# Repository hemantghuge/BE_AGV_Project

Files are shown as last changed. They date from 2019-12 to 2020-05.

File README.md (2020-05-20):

# BE_AGV_Project 2019-2020

## Project Title
Smart and Efficient Techniques for Automated Guided Vehicle

## College
Government College of Engineering and Research, Avasari (Khurd)

## Department
Electronics and Telecommunication Engineering

#### Click below for viewing YouTube video.

YouTube video (https://www.youtube.com/watch?v=_118klFem0o)

## Mentor

**Name:** Dr. Kirti Vasant Thakur
**Email ID:** kirti79@gmail.com

## Members

**Roll No.**: 16131002 **Name:** Aadesh Rambhau Borate **Email ID:** aadeshborate5@gmail.com

**Roll No.:** 16131035 **Name:** Hemant Goraksh Ghuge **Email ID:** hemantgghuge@gmail.com

**Roll No.:** 16131052 **Name:** Unnati Raju Kulkarni **Email ID:** unnatikulkarni46@gmail.com

**Roll No.:** 17231025 **Name:** Revati Anand Kulkarni **Email ID:** kulkarnirevati988@gmail.com

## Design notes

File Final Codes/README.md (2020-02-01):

# NOTE

**Store the final codes as given below:-**

ArduinoMega.ino

RaspberryPi.py

ArduinoNano.ino

NodeMCU.ino

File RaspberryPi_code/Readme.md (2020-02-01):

## NOTE
It is a repository where all the tested code for Raspberry Pi is stored.

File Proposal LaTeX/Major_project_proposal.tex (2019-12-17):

\documentclass[12pt]{article}
\usepackage[utf8]{inputenc}
\usepackage{cite}
\usepackage{graphicx}

\title{Smart and Efficient Techniques for Automated Guided Vehicle}
\author{Team ID 11, eYIC 19-20}
\date{December 2019}

\begin{document}

\maketitle

\section*{Keywords}
eYIC 19-20, SDG, AGV, Machine Vision, PCB, Versatile, Path Planning, Self  Charging, Remote Accessing

\section{Introduction}

Today the automated guided vehicle (AGV) plays an important role in the design and growth of new factories and warehouses. It is a robot that follows markers or wires in the floor or uses vision or lasers.  In an automated process, AGVs are programmed to communicate with other robots to ensure the product is moved smoothly through the warehouse, whether it is being stored for future use or sent directly to shipping areas. Navigation of AGVs is performed through laser, magnetic tapes, machine vision. As per increasing technologies, industries lack adaptive AGVs. That means, AGVs with constant hardware and software upgrades. Lack of vision-based navigation in the AGVs, make them single task-oriented. So, here we are proposing the advanced version of machine vision-based smart automated guided vehicle which incorporates the ML algorithm and would be beneficial for predicting the failures/problem before time and increasing task efficiency and accuracy. The proposed AGV also contains self-charging and can predict the possible future working hours of it. This adaptive AGV is low-cost since it must eventually attract more industries from various fields. Deploying it for repetitive material handling tasks can also allow enterprises to save on labor costs and reassign staff on other essential tasks, such as enhancing customer satisfaction.

\section{Literature Survey}

The automated guided vehicle represents the progress of automation in the industrial field. The first AGV was brought to market in the1950s, by Barrett Electronics \cite{agv_wiki}. Later in 2001, Fujimoto, Tomoya, Jun Ota, Tamio Arai, Tsuyoshi Ueyama, and Tsuyoshi Nishiyama proposed a way of estimation positioning error with magnetic tape to attempt fixed model learning to prevent stationary error while AGV runs iteratively\cite{fujimoto2001}. After in 2006, the authors Vis, Iris FA specify more specific research perspectives in the design and control of AGV systems in distribution and transportation systems. It concluded that new analytical and simulation models need to develop for large AGV systems to overcome large computational time, NP-completeness, congestion, deadlock, and delays in the system and finite planning horizons\cite{iris2006}. According to the research, the global Automated Guided Vehicle (AGV) market size was valued at USD 2.49 billion in 2018 and is projected to expand at a CAGR of 15.8\% from 2019 to 2025”\cite{grandviewresearch_site}. 

\section{Hardware Requirements}

\begin{enumerate}
    \item ATmega2560 Board
    \item Arm Cortex A53 Board
    \item ESP8266 Board
    \item ATmega328p Board
    \item Logitech C270 Webcam
    \item Monster Moto Shield VNH2SP30 Motor Driver 14A (Peak 30A)
    \item Johnson Geared Motor-Grade A Quality-300RPM
    \item MPU-6050 3-Axis Accelerometer and Gyro Sensor
    \item XL4015 5A Step Down Adjustable Power Supply with LED Voltmeter
    \item 58mm Plastic Omni Wheel for Lego
\end{enumerate}

\section{Software Requirements}

\begin{itemize}
  \item Autodesk Fusion
  \item Autodesk Eagle
  \item MATLAB \& Simulink
  \item Arduino IDE
  \item Python IDE
\end{itemize}

\section{Implementation}

Automated guided vehicles are mainly used for the transfer of loads from one place to another in industries. The implementation of proposed AGV is represented using Six modules.

\begin{figure}[htp]
\centering
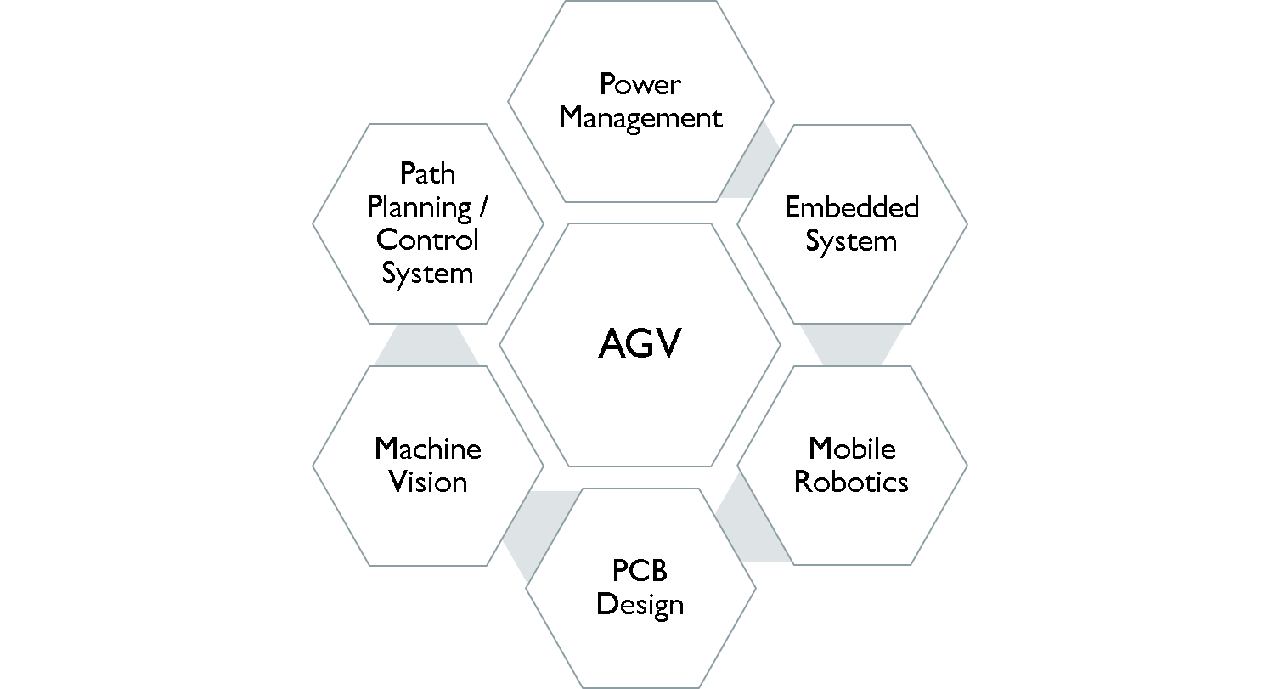
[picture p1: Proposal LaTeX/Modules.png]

\caption{Modules}
\label{fig}
\end{figure}

\begin{itemize}
  \item Power management: To make AGV more efficient the power management unit is integrated, which allows AGV to charge batteries without human interference. MCP 73831 IC is used for charging circuits and power management systems. It also regulates the voltage and current being provided for the whole circuitry of the AGV. Battery level can be indicated using LEDs for manual operation as well. This helps to increase productivity and save time.
  \item Embedded system: It includes ATmega 2660 controller board, Cortex A53 board, communication modules along with supportive software like Arduino IDE, Python IDE, Matlab, etc. Here, ATmega 2560 acts as a master controller. Data administration is done using the ESP8266 module and stored on the cloud.
  \item Pcb design: Self-designed PCB for AGV helps it to work in a multi-domain environment without major hardware changes. It performs power optimization and reduces circuitry. Each module has its own PCB board.
  \item Machine vision:  Machine vision operation is carried out using a web camera and cortex A53 controller board. A self-developed line following algorithm is used for navigation. It also performs obstacle avoidance and prevents occlusion.
  \item Path planning and control system: inertial measurement unit along with PID helps to keep AGV alined. IMU communicates with ATmega 2560 using the i2c bus. DC motor with 300rpm and 6kg-cm is controlled by a VNH2SP30 motor driver.

\end{itemize}
\newpage
\section{Flow Chart}

The working flow of the proposed automated guided vehicle is explained in the below flowchart.

\begin{figure}[htp]
\centering
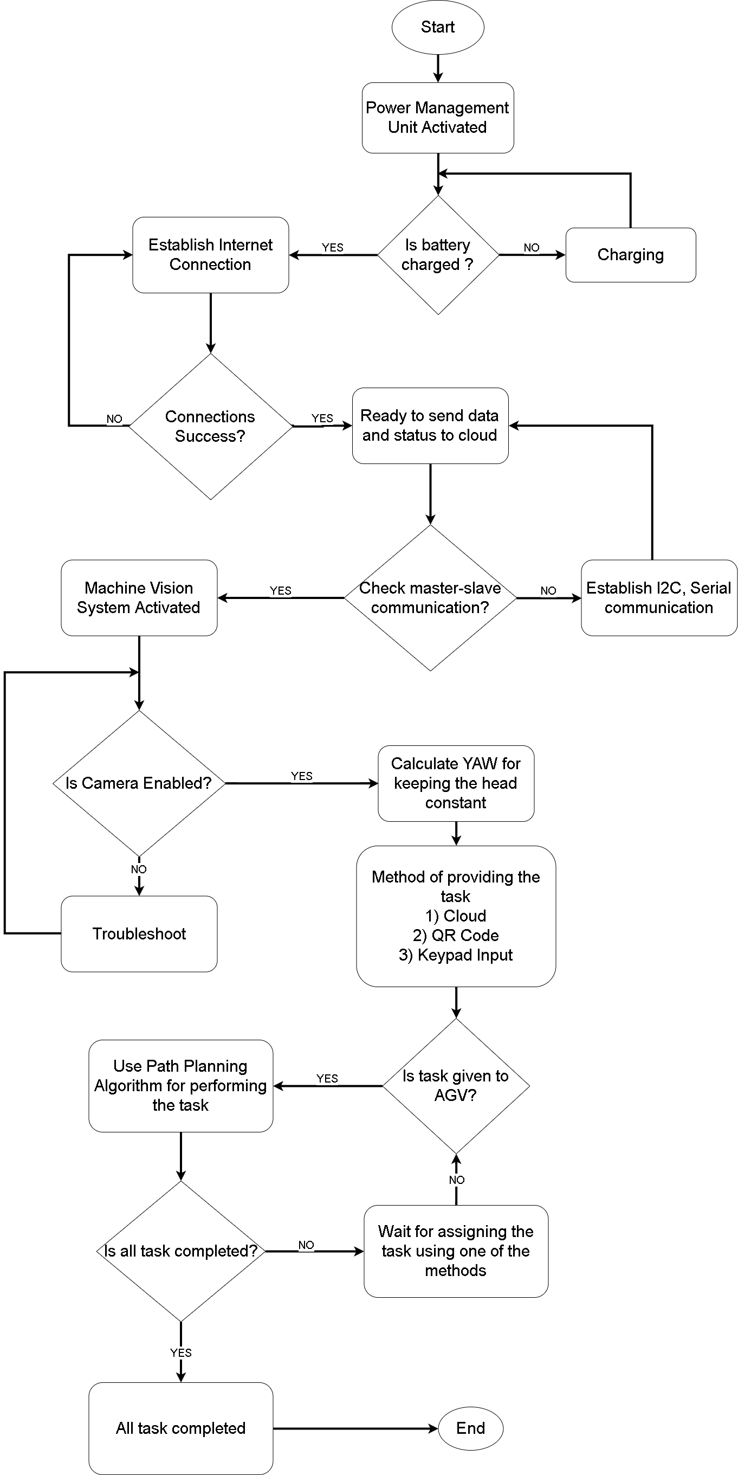
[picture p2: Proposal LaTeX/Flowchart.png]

\caption{Flow Chart}
\label{fig}
\end{figure}
\newpage
\begin{enumerate}
    \item When AGV is assigned a particular task, firstly it checks whether the battery is charged or not. If it is not AGV will move to the charging station and wait till charging.
    \item Once the battery is checked, AGV establishes an internet connection in order to manage data, and check whether the connection is successful or not.
    \item When all these primary tasks are completed, AGV is ready to perform the assigned task.
    \item In order to perform a task, it needs to check the controller’s communication with slaves. If it is ok the working continues. And if not it establishes necessary communication.
    \item For the movement of proposed AGV, it needs machine vision so, firstly it enables the webcam and necessary hardware successfully. A self-developed path planning algorithm is used for navigation.
    \item The task can be given to AGV through remote accessing using the cloud, QR code or keypad input.
    \item After that, AGV checks whether the assigned task is completed or not if not completed, it waits till the completion of the task and checks for the next task.
\end{enumerate}

\section{Feasibility}

The entire concept of AGVs is based on the system of Flexible Manufacturing Systems (FMS). Machine vision and implementation of ML in AGV provide flexibility by activating operational activities in case of any unpredicted problems and issues including data visualization and analyzation. By automating the battery charging operation, several developments to the AGV technology can be enabled for reducing the charging time of the batteries, leading to a further increase in the efficiency and output of the automation. Our self-developed algorithm and PID- controller assures accuracy and stabilization in navigation respectively.

%\cite{agv_wiki}
%\cite{fujimoto2001}
%\cite{iris2006}
%\cite{grandviewresearch_site}
%\cite{isozaki2011}
%\cite{lozoya2007}
%\cite{piyare2011}
%\cite{cardarelli2015}

\bibliographystyle{plain}
\bibliography{ref}

\end{document}

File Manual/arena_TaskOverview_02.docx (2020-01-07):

Automated Guided Vehicle

1.1 Introduction:

Today the Automated guided vehicle plays an important role in the design of new factories and warehouses. In an automated process, AGVs are programmed to communicate with other robots to ensure the product is moved smoothly through the warehouse, whether it is being stored for future use or sent directly to shipping areas. AGV is one kind of transportation that follows the given respective paths and route. It is widely used industrial fields and community services as well as in dangerous working it is able to sense and respond in the given environment.

The first AGV was brought to market in the 1950s, by Barrett Electronics of Northbrook, and at the time it was simply a tow truck that followed a wire in the floor instead of a rail. Over the years the technology has become more sophisticated and today automated vehicles are mainly Laser navigated ex: LGV which works more accurately and precisely in industrial fields, manufacturing processes medical fields. The robot perform hard, dangerous and accurate work in order to make our life easy as they can work for hours without taking rest. They can work without making errors in very less time. The AGV can also store objects on a bed. The objects can be placed on a set of the conveyor and then pushed off by reversing them. Some AGVs use forklifts to lift objects for storage. AGVs are employed in nearly every industry, including, pulp, paper, metals, newspaper, and general manufacturing. Transporting materials such as food, linen or medicine in hospitals is also done. An AGV can also be called a laser guided vehicle (LGV) or self-guided vehicle (SGV). Lower cost versions of AGVs are often called Automated Guided Carts (AGCs) and are usually guided by magnetic tape.

Types of navigation in AGV’S

● Wired navigation - A slot is cut in to the floor and a wire is placed approximately 1 inch below the surface. This slot is cut along the path the AGV is to follow. This wire is used to transmit a radio signal. A sensor is installed on the bottom of the AGV close to the ground. The sensor detects the relative position of the radio signal being transmitted from the wire. This information is used to regulate the steering circuit, making the AGV follow the wire.

● Guide tape navigation - AGVs use tape for the guide path. The AGV is fitted with the appropriate guide sensor to follow the path of the tape. One the major advantage of tape over wired guidance is that can be easily removed and relocated if the course needs to change. Coloured tape is initially less expensive, but lacks the advantage of being embedded in high traffic areas where the tape may become damaged or dirty. The flexible magnetic bar can also be embedded in the floor like wire but works under the same provision as magnetic tape and so remains unpowered or passive. Another advantage of magnetic guide tape is the dual polarity.

● Laser target navigation - The navigation is done by mounting reflective tape on walls, poles or fixed machines. The AGV carries a laser transmitter and receiver on a rotating turret. The laser is transmitted and received by the same sensor. The angle and (sometimes) distance to any reflectors that in line of sight and in range are automatically calculated. This information is compared to the map of the reflector layout stored in the AGV’s memory. This allows the navigation system to triangulate the current position of the AGV. The current position is compared to the path programmed in to the reflector layout map. The steering is adjusted accordingly to keep the AGV on track. It can then navigate to a desired target using the constantly updating position

1.2 Arena:

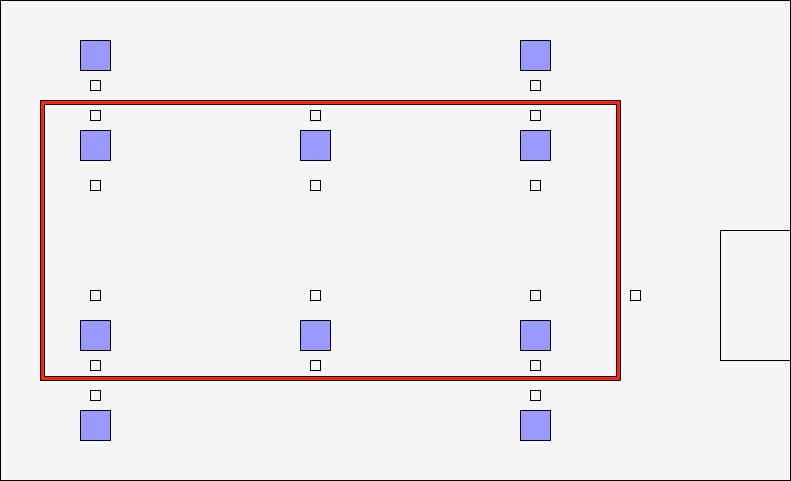
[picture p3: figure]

Battery charging

D

C

B

A

Fig 1

For the demonstration of our project, here is the prototype of a warehouse. Blue boxes indicate the locations to and from which material is transported from one position to another. Red line marked is the line on which the AGV can travel using sensors or machine vision. The smaller boxes on either side of the line as well as in the front of blue boxes represent QR codes with which path planning and actions to be performed can be decided.

1.3 Tasks:

There are 3 sections in which the demonstration is divided. Let us call them D1, D2, D3 for the sake of convenience.

1. D1:

Here AGV will use machine vision for the line following application. This will be demonstrated on the red line shown in the figure1. QR codes on the either side of the line are used for decision of pick or place. A, B, C, D are the positions for pick and place application. Side arms present on either side of the AGV are used for it. Configured QR codes pasted on the floor will work as feedback in decision making.

2. D2:

This section will be demonstrated in the internal part of red line. Here we are mainly focusing on the path planning algorithm. Node numbers or values are predefined for the positions in the QR code. By using By using an user interface and IoT platform, start point and destination points are provided to AGV. The optimum path will be decided by the AGV itself. A load cell is used as a feedback to prevent overloading condition.

3. D3:

This is the more advanced feature of AGV. Here AGV will follow a particular person. Machine learning algorithm will be implemented for the same. Also the load cell is used for the preventing overloading.

4. D4:

This is the self-charging feature in which the low battery level will be detected and it will move automatically towards battery charging station. The position of the battery charging station will be decided by a special QR code.

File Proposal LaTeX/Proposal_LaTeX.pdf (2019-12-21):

# Smart and Efficient Techniques for Automated Guided Vehicle

### Team ID 11, eYIC 19-20

### December 2019

## Keywords

eYIC 19-20, SDG, AGV, Machine Vision, PCB, Versatile, Path Planning, Self Charging, Remote Accessing

## 1 Introduction

Today the automated guided vehicle (AGV) plays an important role in the design and growth of new factories and warehouses. It is a robot that follows markers or wires in the floor or uses vision or lasers. In an automated process, AGVs are programmed to communicate with other robots to ensure the product is moved smoothly through the warehouse, whether it is being stored for future use or sent directly to shipping areas. Navigation of AGVs is performed through laser, magnetic tapes, machine vision. As per increasing technologies, industries lack adaptive AGVs. That means, AGVs with constant hardware and software upgrades. Lack of vision-based navigation in the AGVs, make them single task-oriented. So, here we are proposing the advanced version of machine vision-based smart automated guided vehicle which incorporates the ML algorithm and would be beneficial for predicting the failures/problem before time and increasing task efficiency and accuracy. The proposed AGV also contains self-charging and can predict the possible future working hours of it. This adaptive AGV is low-cost since it must eventually attract more industries from various fields. Deploying it for repetitive material handling tasks can also allow enterprises to save on labor costs and

1

reassign staff on other essential tasks, such as enhancing customer satisfaction.

## 2 Literature Survey

The automated guided vehicle represents the progress of automation in the industrial field. The first AGV was brought to market in the1950s, by Barrett Electronics [4]. Later in 2001, Fujimoto, Tomoya, Jun Ota, Tamio Arai, Tsuyoshi Ueyama, and Tsuyoshi Nishiyama proposed a way of estimation positioning error with magnetic tape to attempt fixed model learning to prevent stationary error while AGV runs iteratively [1]. After in 2006, the authors Vis, Iris FA specify more specific research perspectives in the design and control of AGV systems in distribution and transportation systems. It concluded that new analytical and simulation models need to develop for large AGV systems to overcome large computational time, NP-completeness, congestion, deadlock, and delays in the system and finite planning horizons [2]. According to the research, the global Automated Guided Vehicle (AGV) market size was valued at USD 2.49 billion in 2018 and is projected to expand at a CAGR of 15.8% from 2019 to 2025” [3].

## 3 Hardware Requirements

1. ATmega2560 Board
2. Arm Cortex A53 Board
3. ESP8266 Board
4. ATmega328p Board
5. Logitech C270 Webcam
6. Monster Moto Shield VNH2SP30 Motor Driver 14A (Peak 30A)
7. Johnson Geared Motor-Grade A Quality-300RPM
8. MPU-6050 3-Axis Accelerometer and Gyro Sensor
9. XL4015 5A Step Down Adjustable Power Supply with LED Voltmeter
10. 58mm Plastic Omni Wheel for Lego

2

## 4 Software Requirements

- Autodesk Fusion
- Autodesk Eagle
- MATLAB & Simulink
- Arduino IDE
- Python IDE

## 5 Implementation

Automated guided vehicles are mainly used for the transfer of loads from one place to another in industries. The implementation of proposed AGV is represented using Six modules.

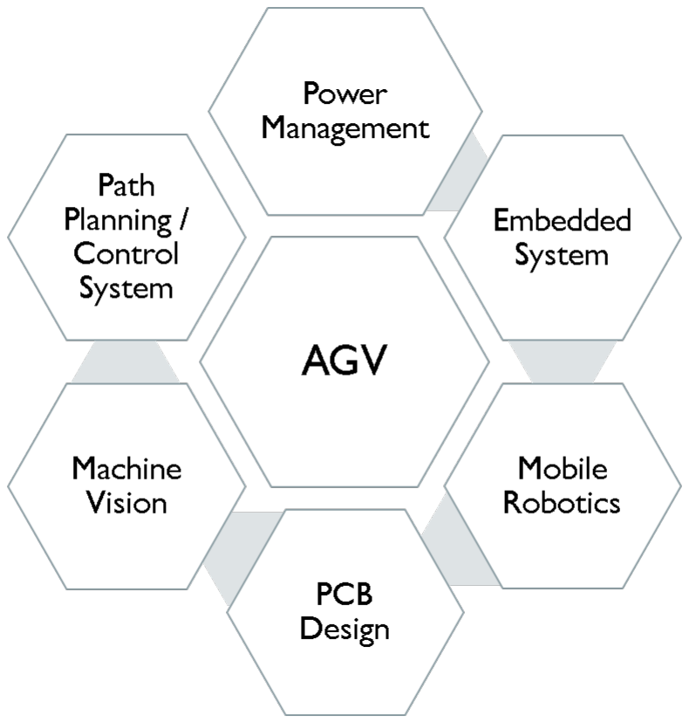
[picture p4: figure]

Figure 1: Modules

3

- Power management: To make AGV more efficient the power management unit is integrated, which allows AGV to charge batteries without human interference. MCP 73831 IC is used for charging circuits and power management systems. It also regulates the voltage and current being provided for the whole circuitry of the AGV. Battery level can be indicated using LEDs for manual operation as well. This helps to increase productivity and save time.
- Embedded system: It includes ATmega 2660 controller board, Cortex A53 board, communication modules along with supportive software like Arduino IDE, Python IDE, Matlab, etc. Here, ATmega 2560 acts as a master controller. Data administration is done using the ESP8266 module and stored on the cloud.
- Pcb design: Self-designed PCB for AGV helps it to work in a multidomain environment without major hardware changes. It performs power optimization and reduces circuitry. Each module has its own PCB board.
- Machine vision: Machine vision operation is carried out using a web camera and cortex A53 controller board. A self-developed line following algorithm is used for navigation. It also performs obstacle avoidance and prevents occlusion.
- Path planning and control system: inertial measurement unit along with PID helps to keep AGV alined. IMU communicates with ATmega 2560 using the i2c bus. DC motor with 300rpm and 6kg-cm is controlled by a VNH2SP30 motor driver.

4

## 6 Flow Chart

The working flow of the proposed automated guided vehicle is explained in the below flowchart.

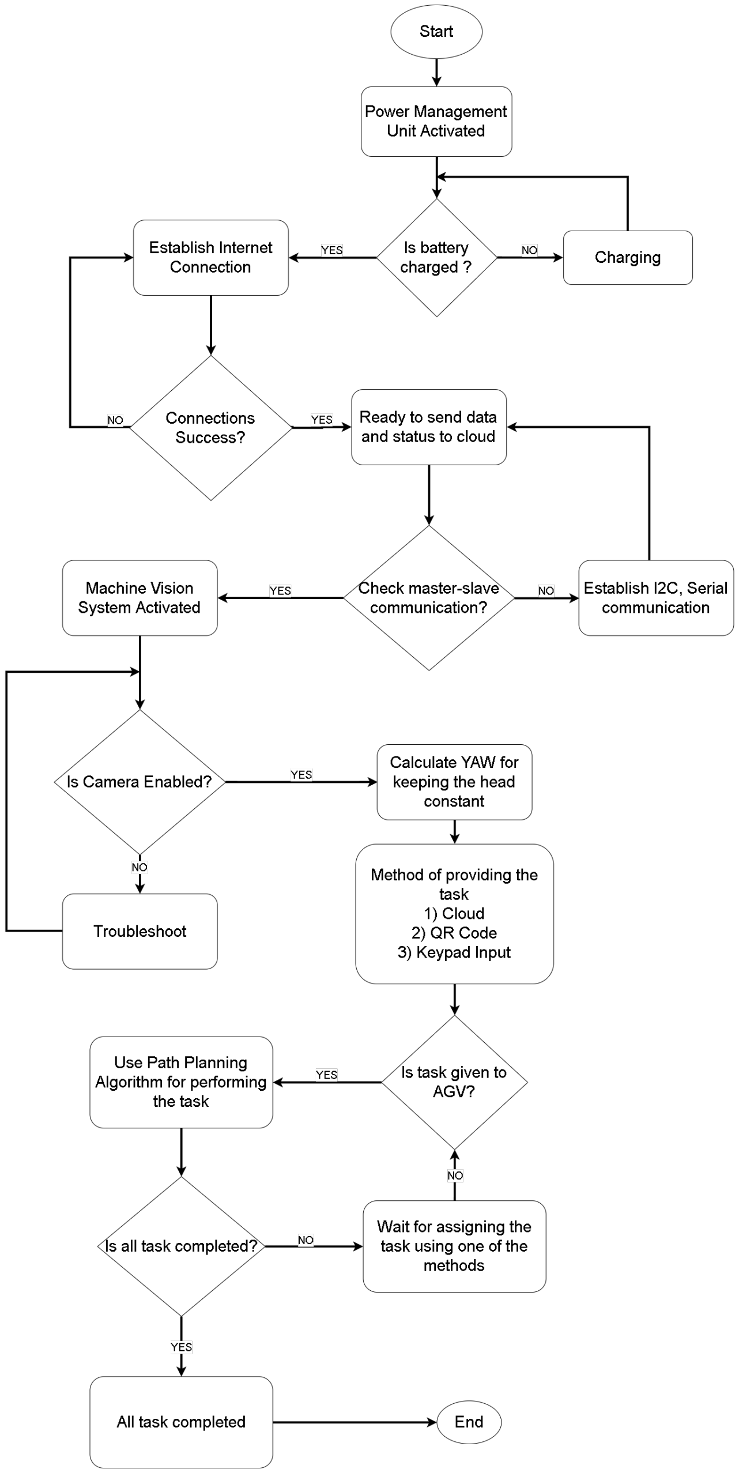
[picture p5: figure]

Figure 2: Flow Chart

5

1. When AGV is assigned a particular task, firstly it checks whether the battery is charged or not. If it is not AGV will move to the charging station and wait till charging.
2. Once the battery is checked, AGV establishes an internet connection in order to manage data, and check whether the connection is successful or not.
3. When all these primary tasks are completed, AGV is ready to perform the assigned task.
4. In order to perform a task, it needs to check the controller’s communication with slaves. If it is ok the working continues. And if not it establishes necessary communication.
5. For the movement of proposed AGV, it needs machine vision so, firstly it enables the webcam and necessary hardware successfully. A self-developed path planning algorithm is used for navigation.
6. The task can be given to AGV through remote accessing using the cloud, QR code or keypad input.
7. After that, AGV checks whether the assigned task is completed or not if not completed, it waits till the completion of the task and checks for the next task.

## 7 Feasibility

The entire concept of AGVs is based on the system of Flexible Manufacturing Systems (FMS). Machine vision and implementation of ML in AGV provide flexibility by activating operational activities in case of any unpredicted problems and issues including data visualization and analyzation. By automating the battery charging operation, several developments to the AGV technology can be enabled for reducing the charging time of the batteries, leading to a further increase in the efficiency and output of the automation. Our self-developed algorithm and PID- controller assures accuracy and stabilization in navigation respectively.

6

## References

[1] Fujimoto, Tomoya, Jun Ota, Tamio Arai, Tsuyoshi Ueyama, and Tsuyoshi Nishiyama. Semi-guided navigation of agv through iterative learning. Intelligent Robot and Systems, IEEE/RSJ International Conference, 2:968–973, 2001.
[2] A. Vis Iris, F. Survey of research in the design and control of automated guided vehicle systems. European Journal of Operational Research, 170:677–709, 2006.
[3] Grand View Research. Automated guided vehicle agv market, 2019.
[4] Wikipedia. Automated guided vehicle, 2012.

7

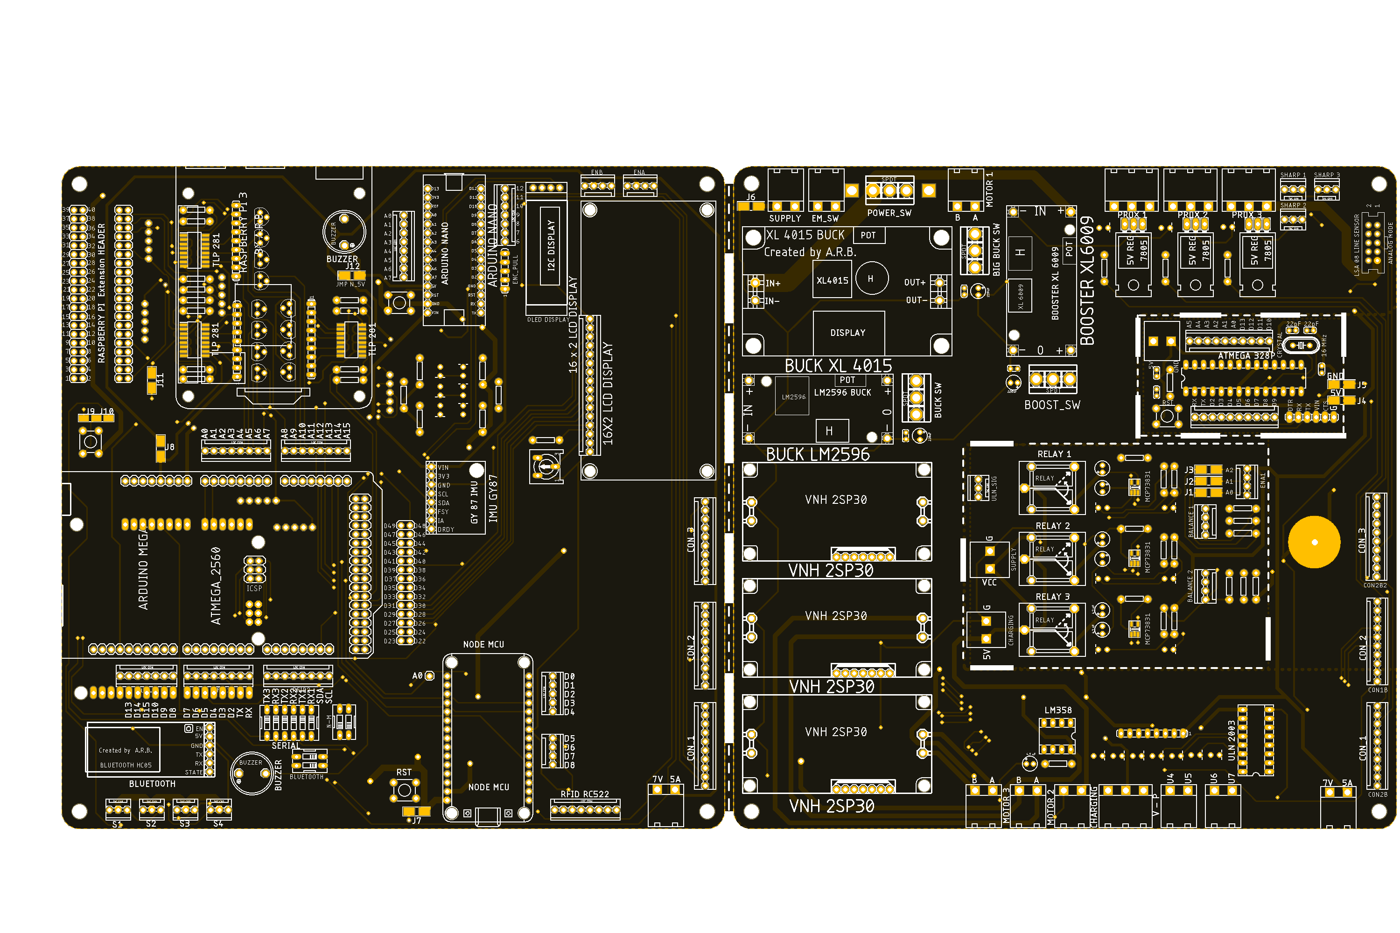
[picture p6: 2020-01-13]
PCB Files/PCB IMAGE/BLACK.png

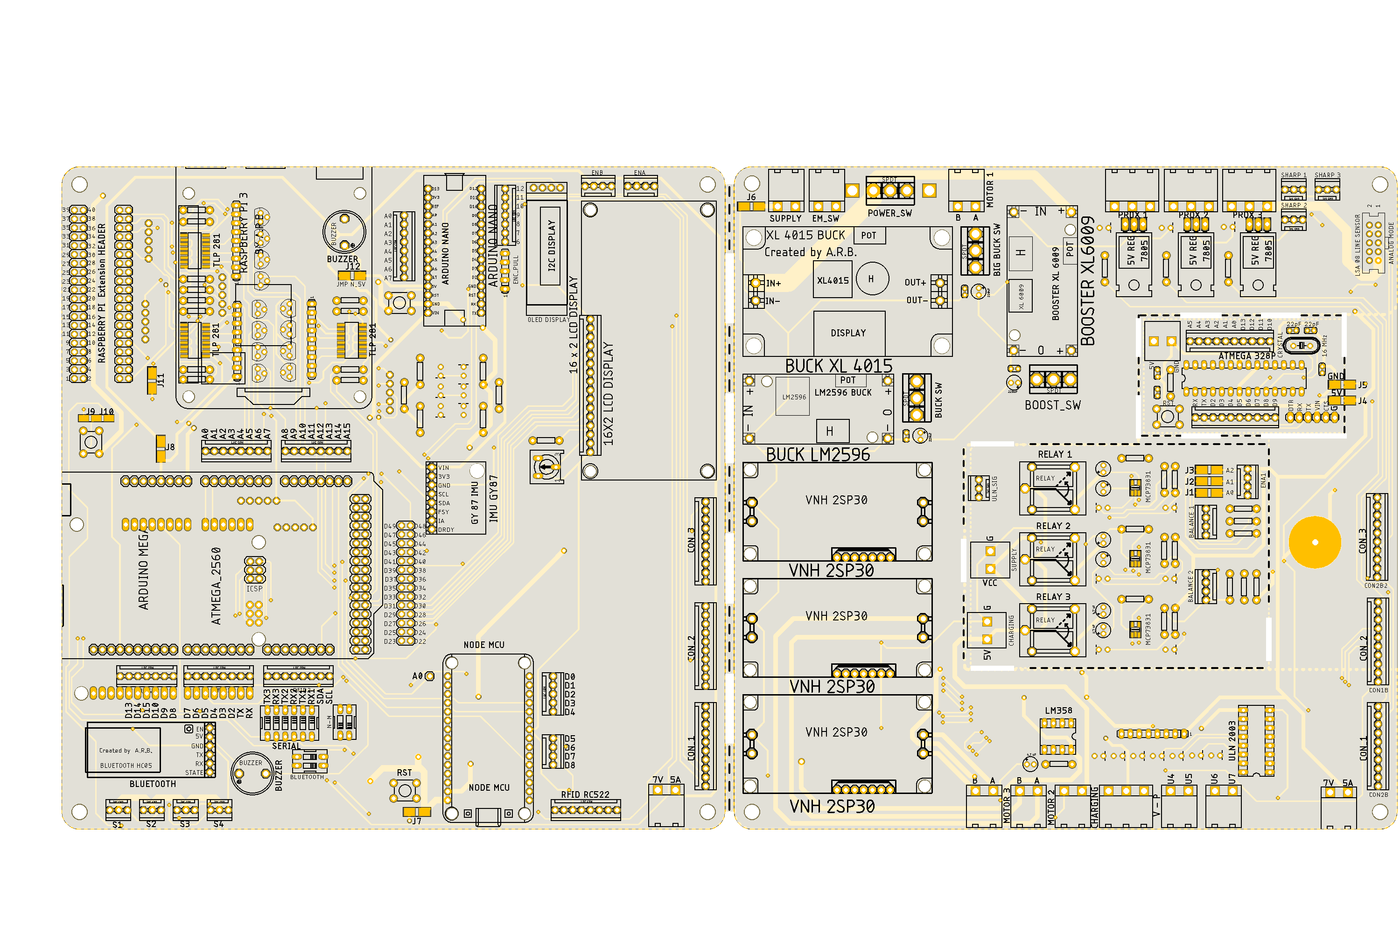
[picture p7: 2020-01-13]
PCB Files/PCB IMAGE/WHITE.png

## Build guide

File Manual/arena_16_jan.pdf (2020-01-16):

# Smart and Efficient Techniques for Automated Guided Vehicle

# 1. Arena:

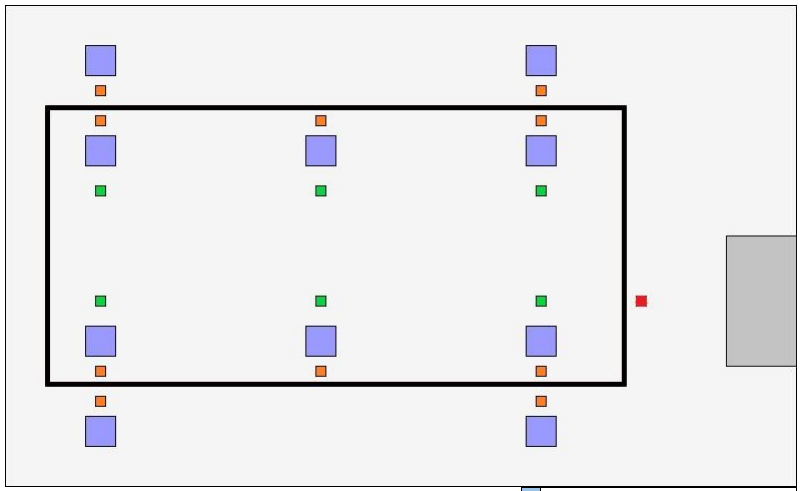
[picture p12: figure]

### Fig 1

Length * Breadth = 3300 mm * 2500 mm

There are 3 sections in which the demonstration is divided. Let us call them D1, D2, D3 for the sake of convenience.

1. D1:
Here AGV will use machine vision for the line following application. This will be demonstrated on the black line shown in the Fig 1. QR codes on the either side of the line are used for decision of pick or place. Side arms present on either side of the AGV are used for it. Configured QR codes pasted on the floor will work as feedback in decision making.

Boxes (70*70*70)
D1 QR Code(40*40)
D2 QR Code(40*40)
QR Code for battery charging Charging section

2. D2:
This section will be demonstrated in the internal part of black line. Here we are mainly focusing on the path planning algorithm. Node numbers or values are predefined for the positions in the QR code. By using user interface and IoT platform, start point and destination points are provided to AGV. The optimum path will be decided by the AGV itself. A load cell is used as a feedback to prevent overloading condition.
3. D3:
Here AGV will follow a particular person. Machine learning algorithm will be implemented for the same. Also the load cell is used for the preventing overloading.
4. D4:
This is the self-charging feature in which the low battery level will be detected and it will move automatically towards battery charging station. The position of the battery charging station will be decided by a special QR code (red box in Fig 1).

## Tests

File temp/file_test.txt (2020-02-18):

nTest file
git 
AGV
new
testing file

test 1
ready

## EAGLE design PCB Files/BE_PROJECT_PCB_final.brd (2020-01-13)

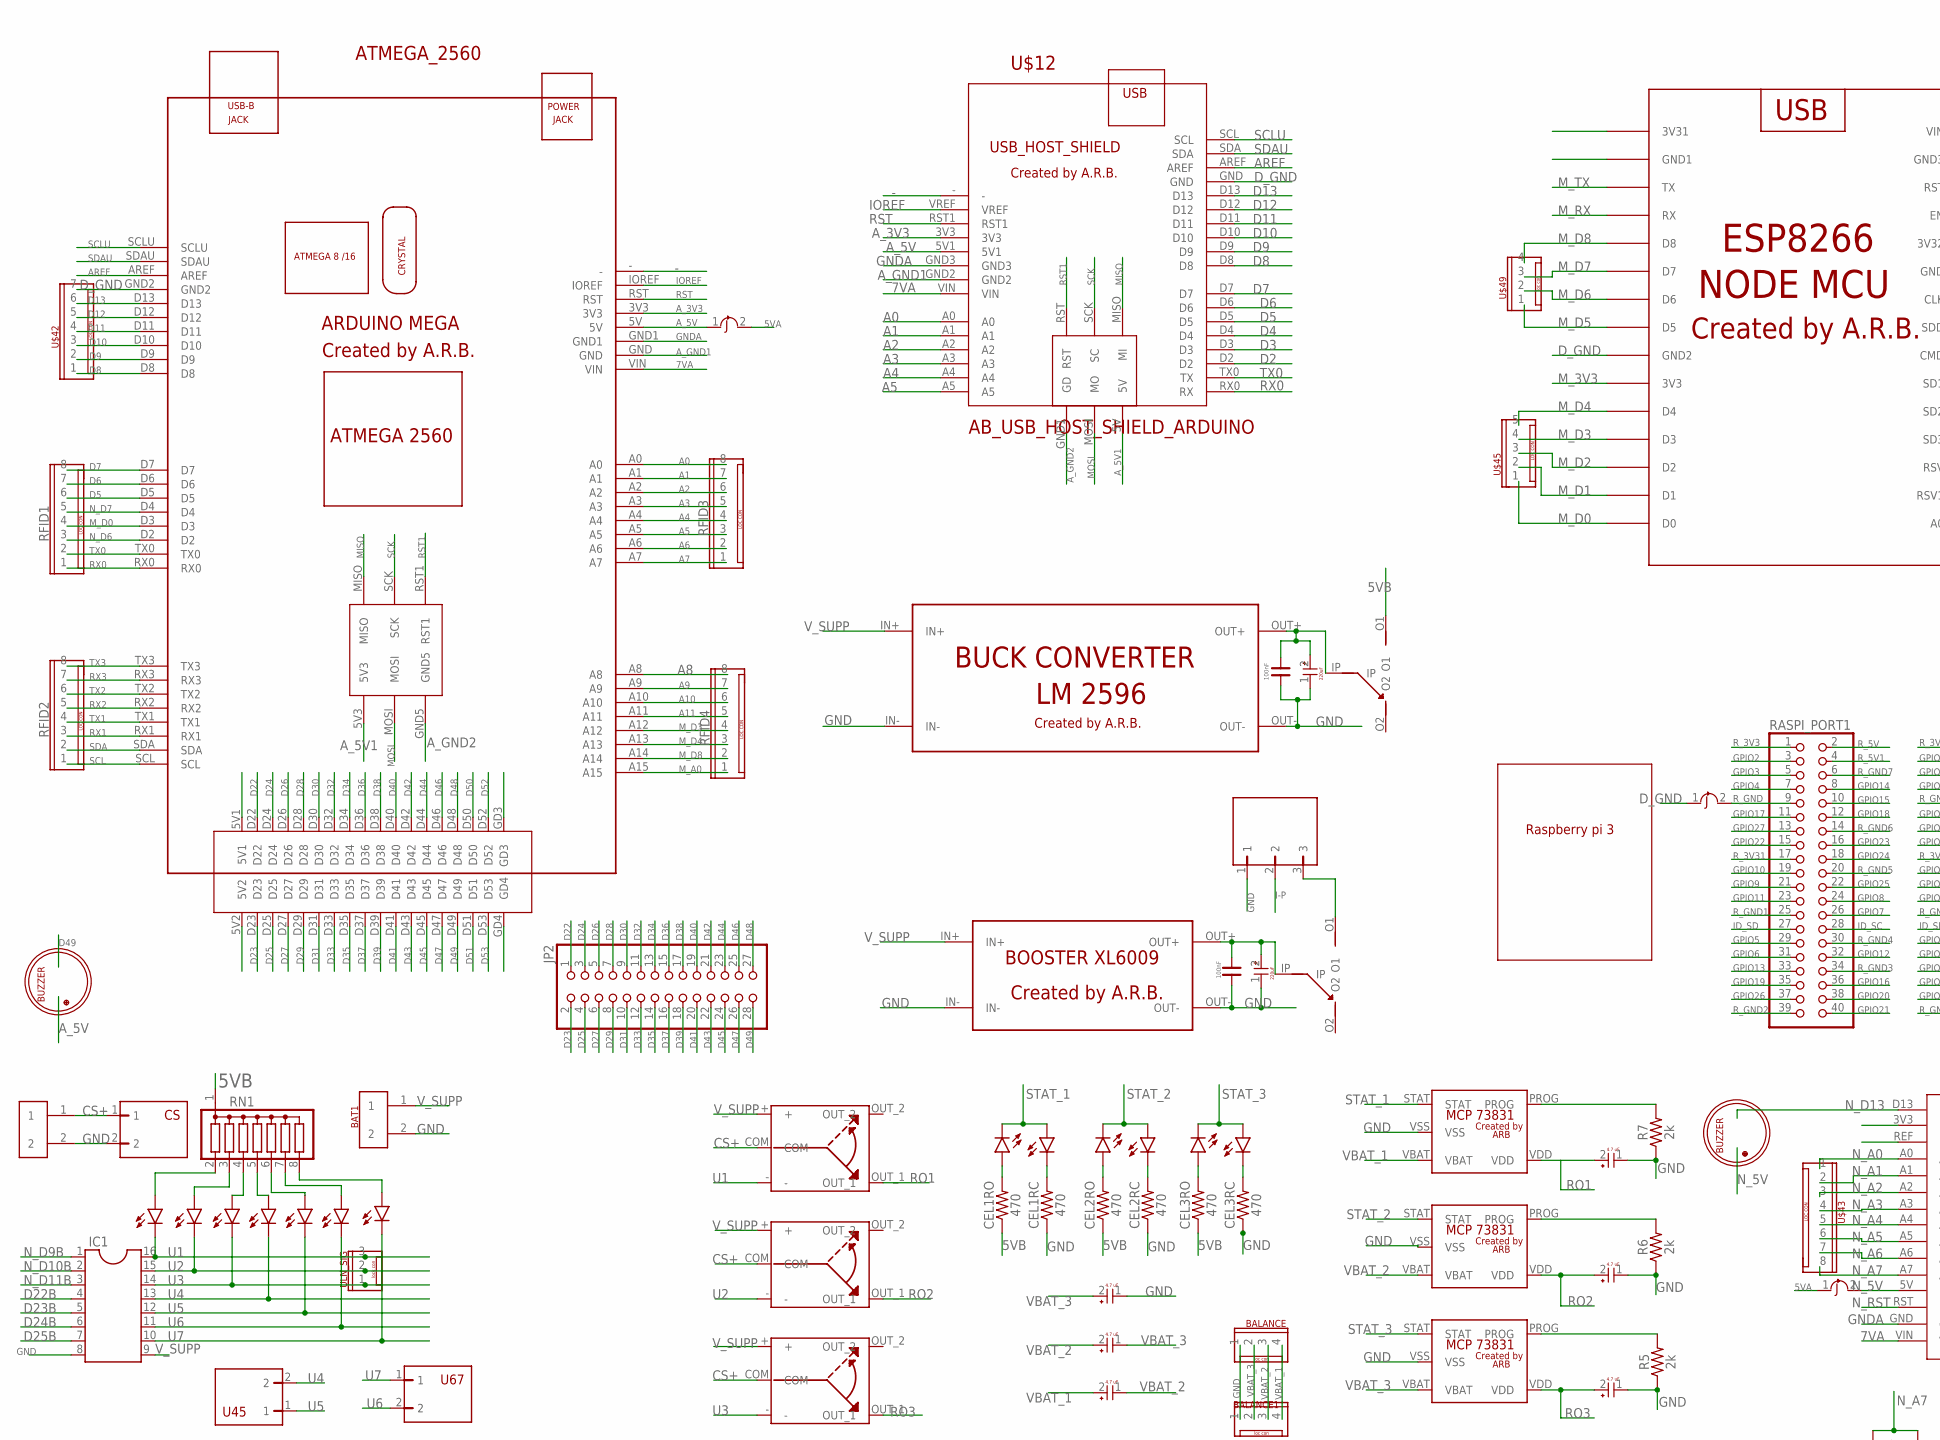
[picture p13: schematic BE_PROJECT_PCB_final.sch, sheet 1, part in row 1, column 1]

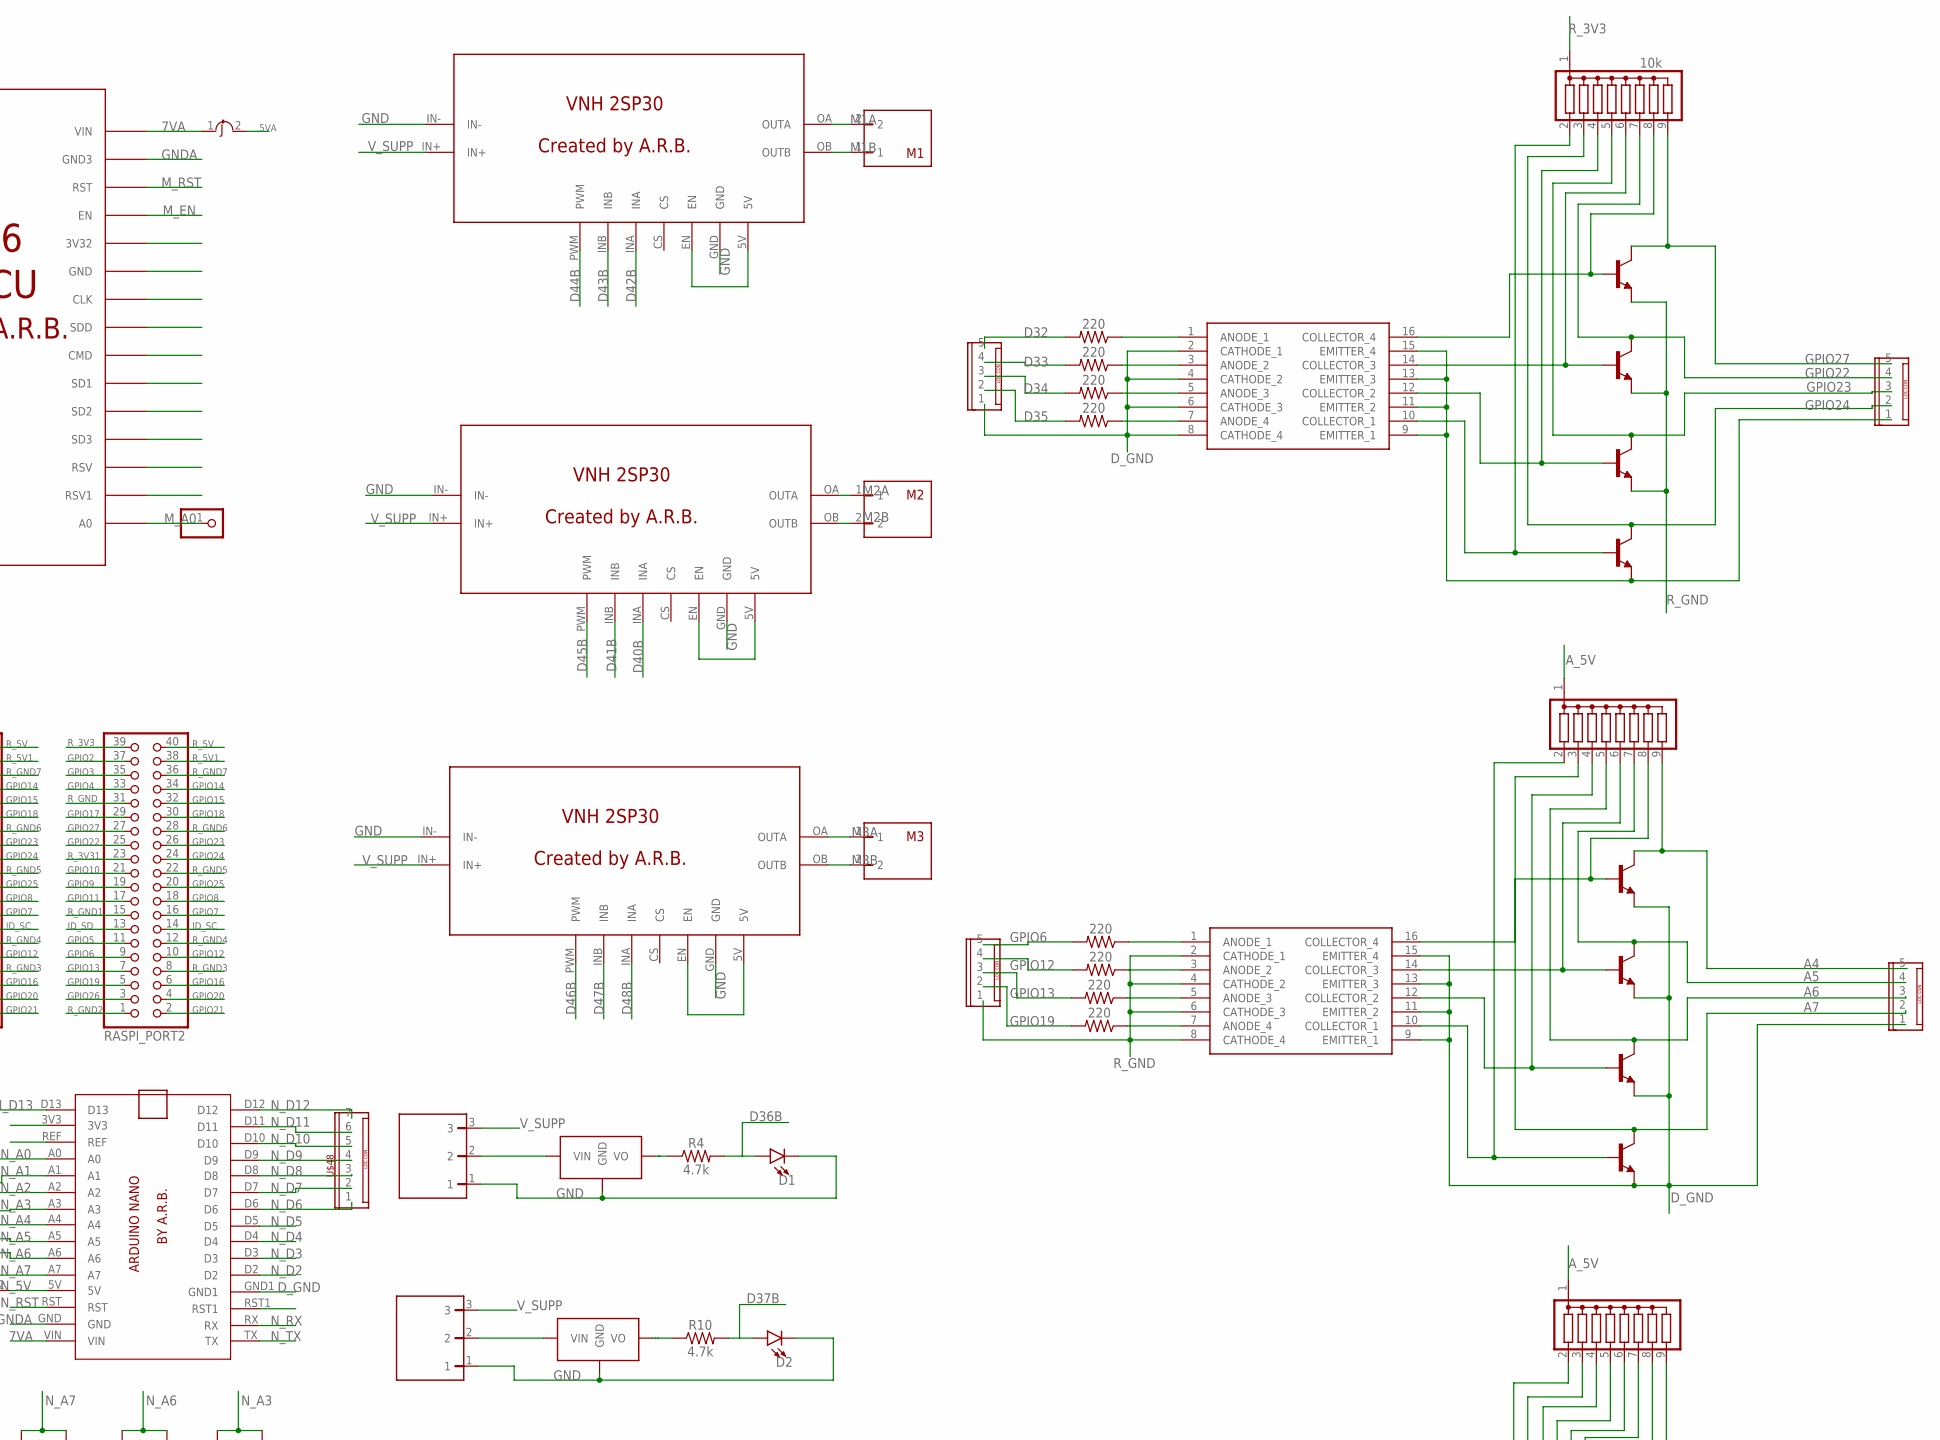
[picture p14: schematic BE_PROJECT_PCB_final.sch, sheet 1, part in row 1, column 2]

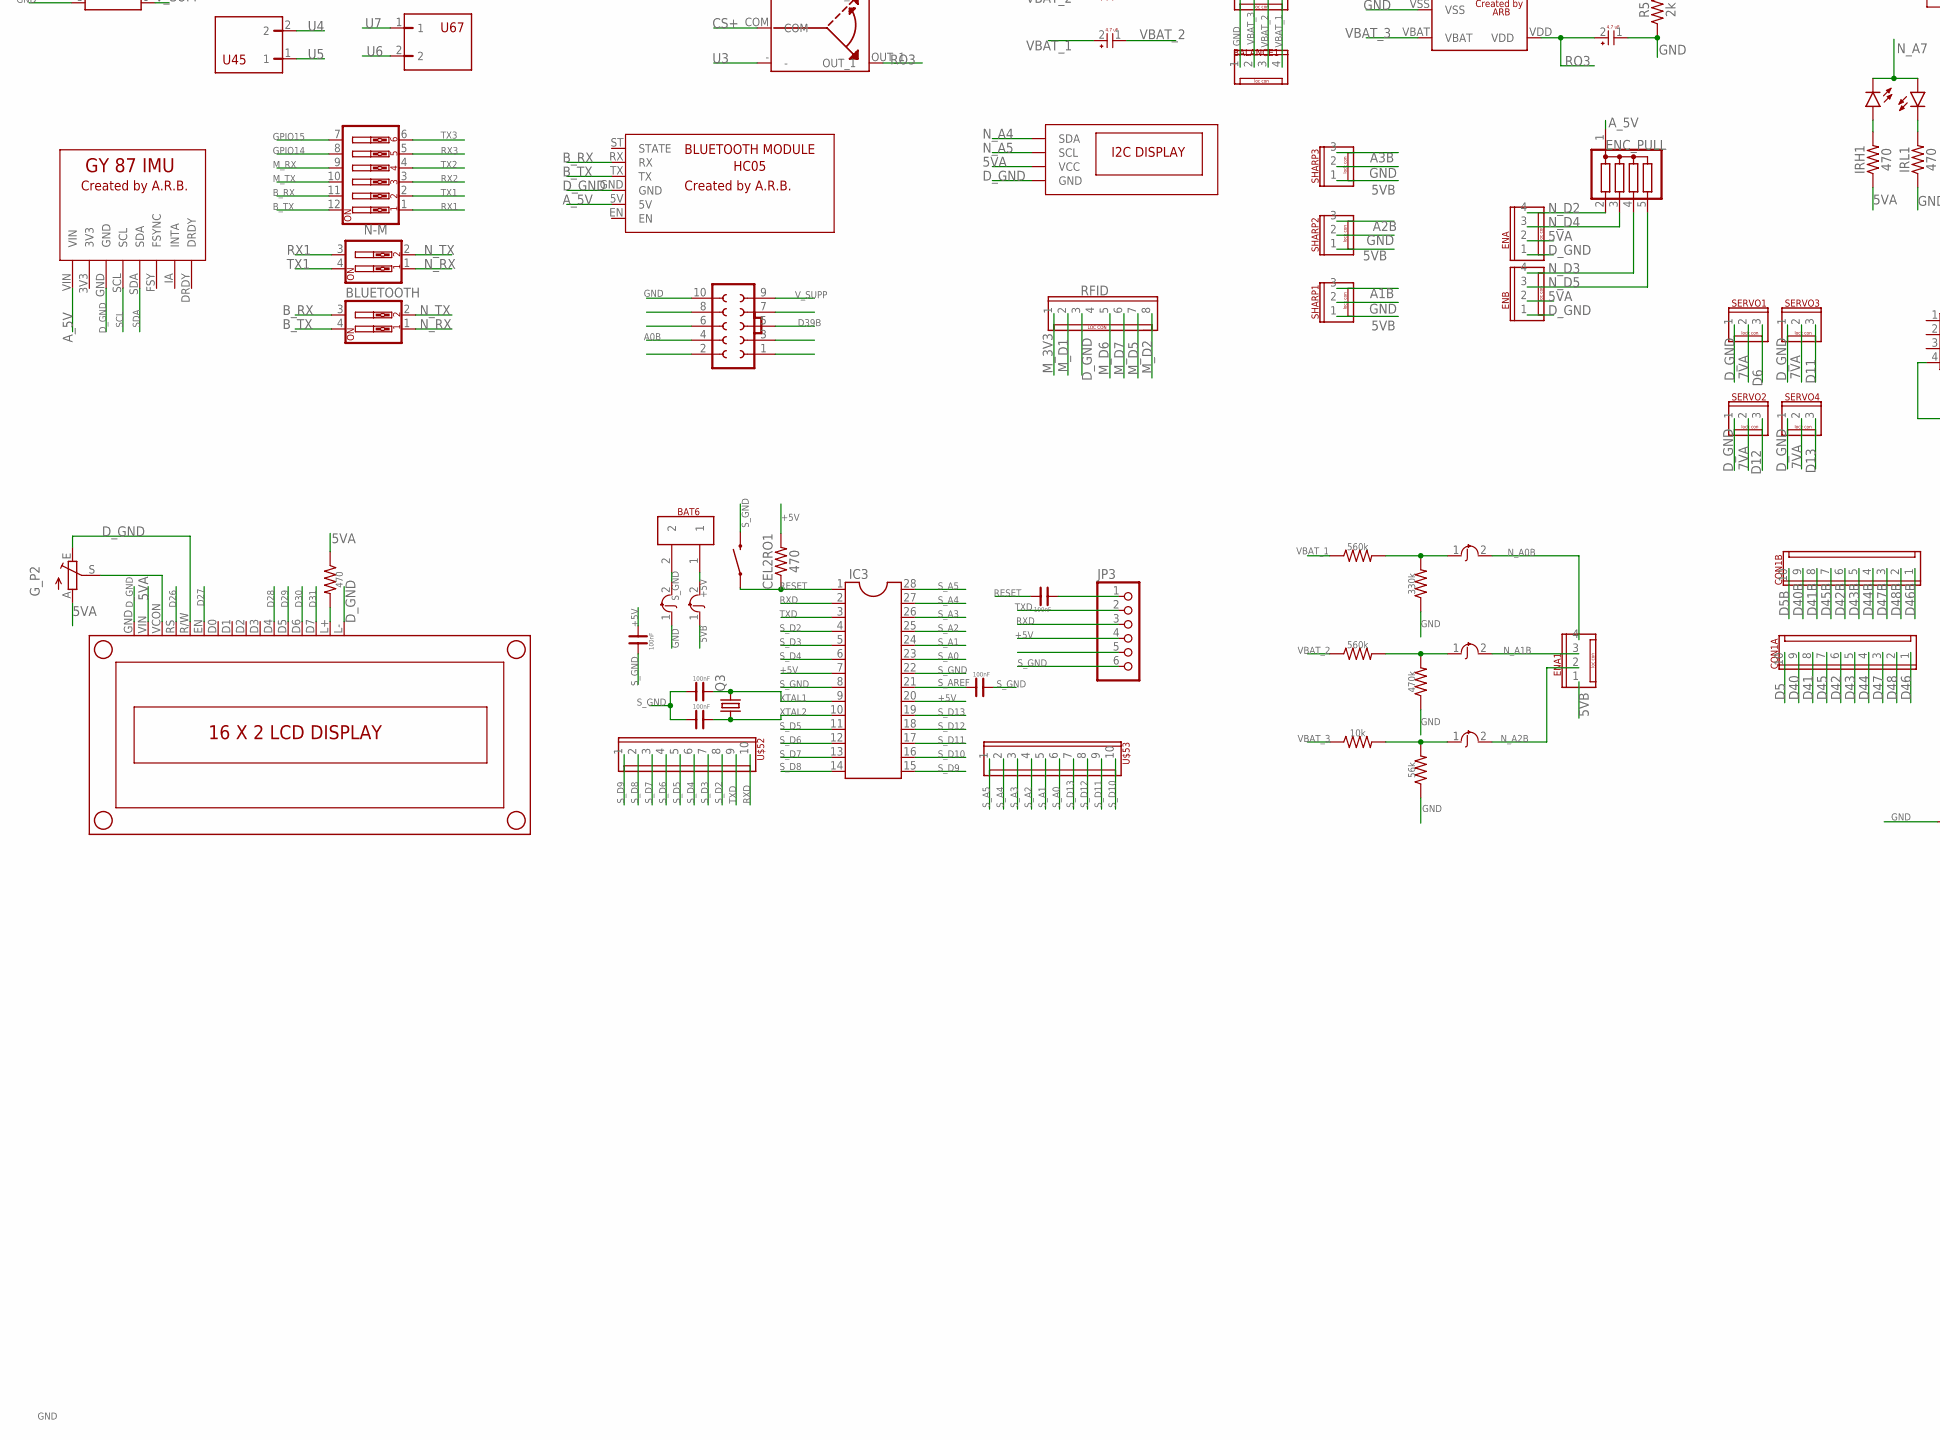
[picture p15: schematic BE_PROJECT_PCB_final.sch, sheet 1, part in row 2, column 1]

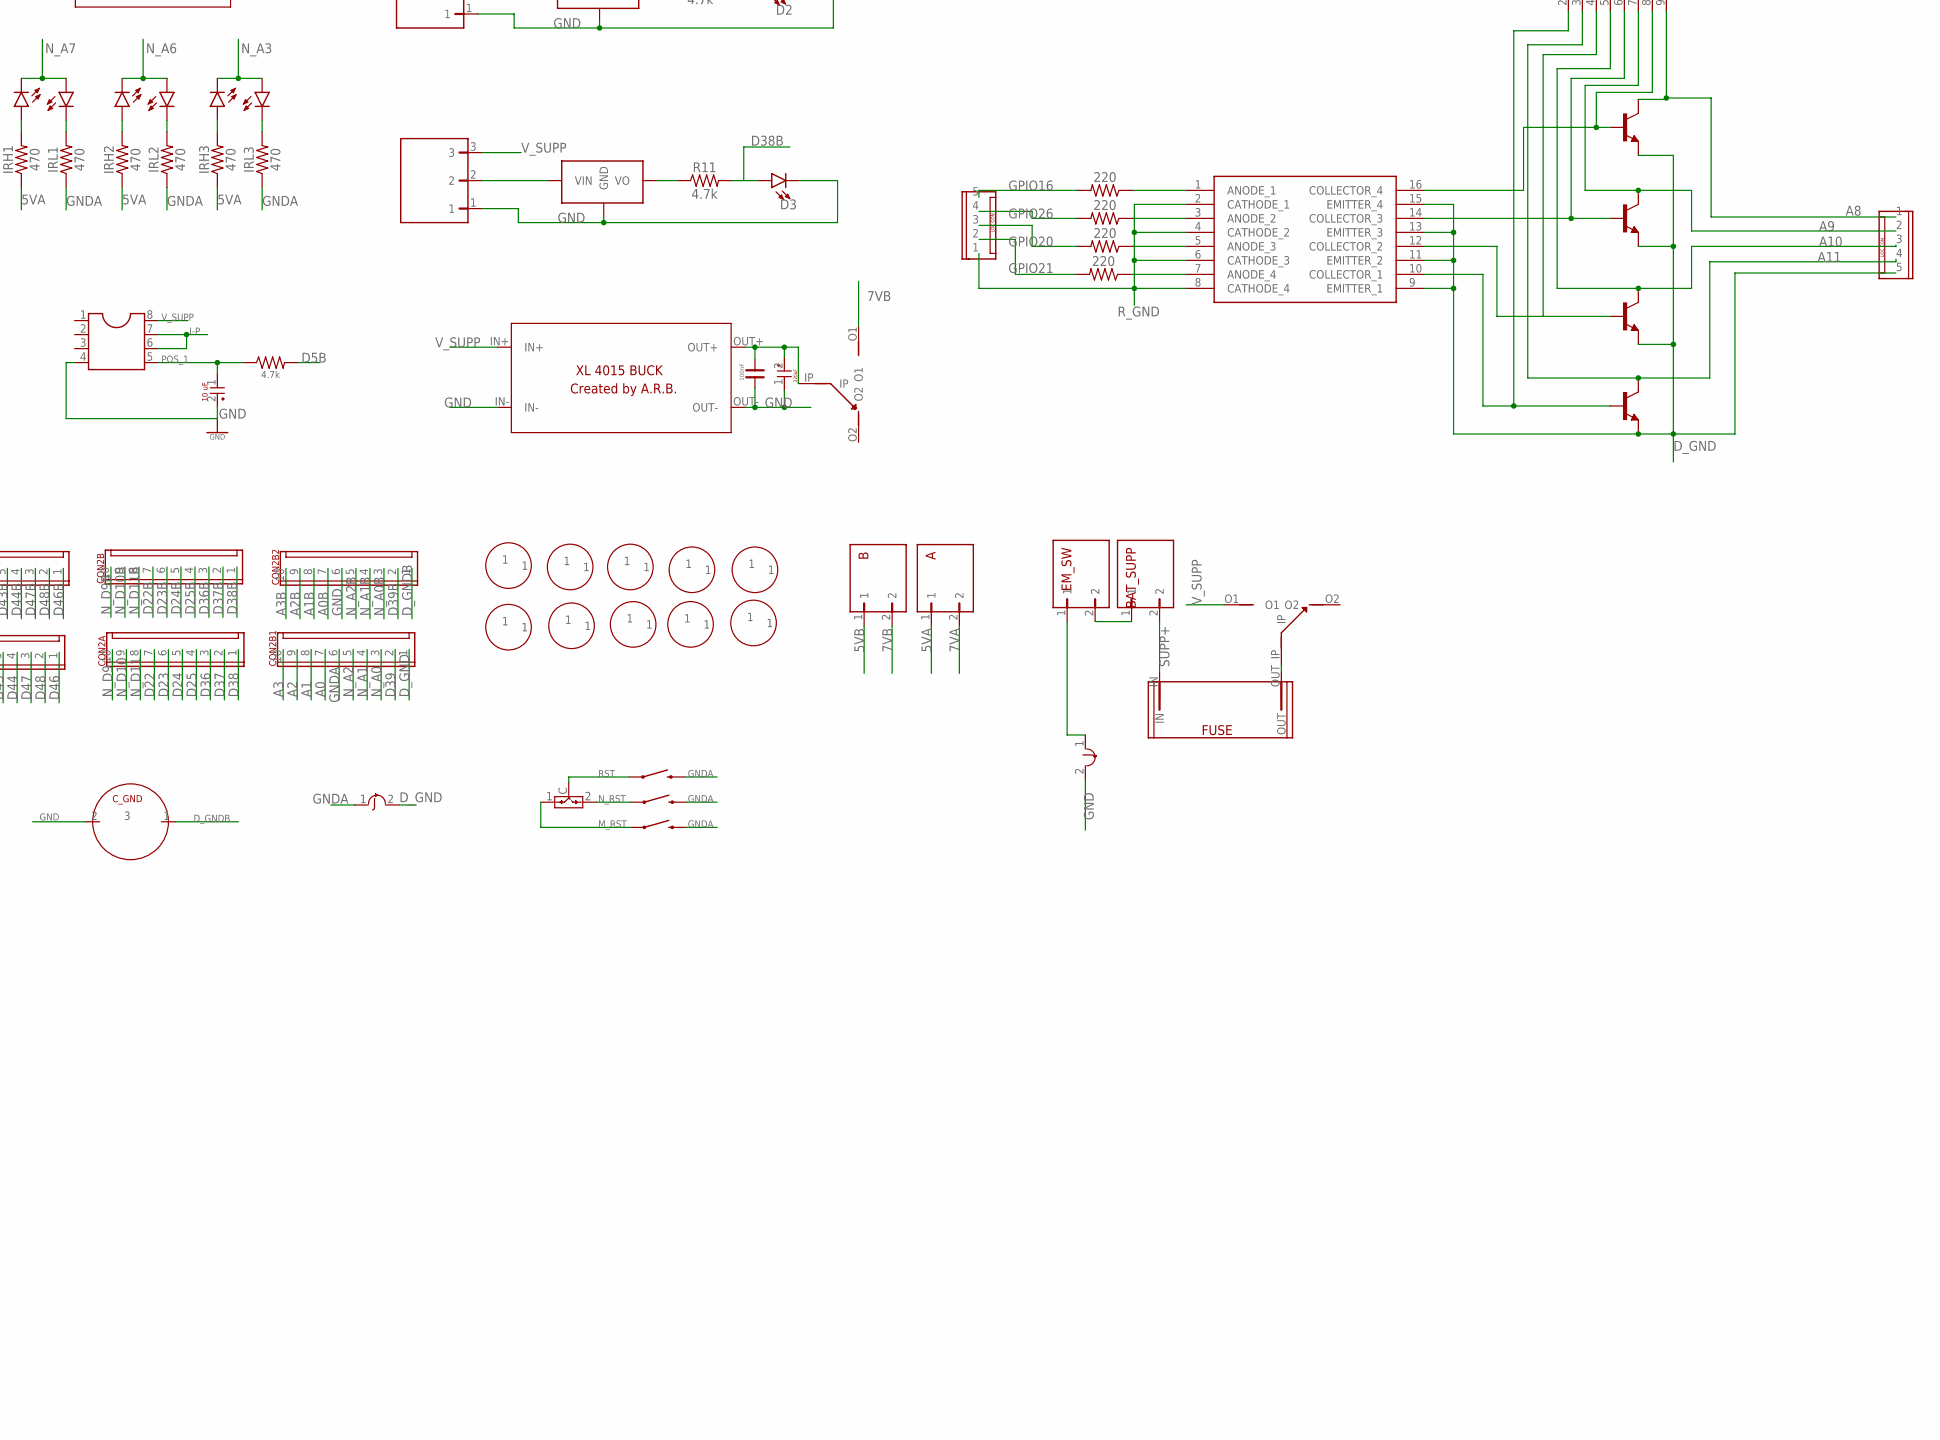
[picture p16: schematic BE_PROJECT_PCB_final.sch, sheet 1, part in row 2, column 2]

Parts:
10K: 10k; SIL9
A: AB_RIGHT_TER_BLK
ATMEGA_2560: AB_ARDUINO_MEGA
B: AB_RIGHT_TER_BLK
BALANCE, BALANCE1: AB_4PIN_LOC_CONNECTOR
BAT1, BAT6: AB_SCREW_TERMINAL_5MM_2PIN
BAT_SUPP: AB_RIGHT_TER_BLK
BC547: BC547; TO92
BLUETOOTH: SW_DIP-2; EDG-02
C1, C2, C3, C4, C5, C6, C7, C8: 100nF; C020-035X018
CEL1CC, CEL1CO, CEL2CC, CEL2CO, CEL3CC, CEL3CO: LED-3MM-NO_SILK; LED_3MM-NS
CEL1RC, CEL1RO, CEL2RC, CEL2RO, CEL2RO1, CEL3RC, CEL3RO: 470; AXIAL-0.3
CON1A, CON1B, CON2A, CON2B, CON2B1, CON2B2: AB_10PIN_LOC_CONNECTOR
CS: AB_RIGHT_TER_BLK
C_GND: AB_JOINT_GND
D1, D2, D3: LED-3MM-NO_SILK; LED_3MM-NS
EM_SW: AB_RIGHT_TER_BLK
ENA, ENA1: AB_4PIN_LOC_CONNECTOR
ENB: AB_4PIN_LOC_CONNECTOR
ENC_PULL: G04R; SIL5
FUSE: AB_FUSE_HOLDER
G_P2: TRIM_EU-RS3; RS3
IC1: DIL16S; SOCKET-16
IC2: DIL8S; SOCKET-08
IC3: DIL28-3
IC8, IC9, IC10: TLP281-4(GB,J,F); SOIC127P700X210-16N
IH1, IH2, IH3: LED-3MM-NO_SILK; LED_3MM-NS
IL1, IL2, IL3: LED-3MM-NO_SILK; LED_3MM-NS
IRH1, IRH2, IRH3: 470; AXIAL-0.3
IRL1, IRL2, IRL3: 470; AXIAL-0.3
JP1: PINHD-1X1; 1X01
JP2: PINHD-2X14; 2X14
JP3: PINHD-1X6; 1X06
L1, L2, L3, L4, L5, L6, L7: LED-3MM-NO_SILK; LED_3MM-NS
LSA_2: LSA1; S10V
M1, M2, M3: AB_RIGHT_TER_BLK
MEGA_RST, MEGA_RST1: MOMENTARY-SWITCH-SPST-PTH-6.0MM; TACTILE_SWITCH_PTH_6.0MM
M_RST: MOMENTARY-SWITCH-SPST-PTH-6.0MM; TACTILE_SWITCH_PTH_6.0MM
N-M: SW_DIP-2; EDG-02
NANO: AB_JUMPER_ONE_WAY
NODEMCU: AB_JUMPER_ONE_WAY
N_RST: MOMENTARY-SWITCH-SPST-PTH-6.0MM; TACTILE_SWITCH_PTH_6.0MM
OISO1, OISO2, OISO3, OISO4, OISO5, OISO6: AB_5PIN_LOC_CONNECTOR
PPR_R1: 4.7k; AXIAL-0.3
PROX1, PROX2, PROX3: AB_RIGHT_TER_BLK_3PIN
Q3: CRYSTALHC49U-V; HC49U-V
R2, R35: 560k; AXIAL-0.3
R4, R10, R11: 4.7k; AXIAL-0.3
R5, R6, R7: 2k; AXIAL-0.3
R17: 470; AXIAL-0.3
R18, R19, R20, R21, R22, R23, R24, R25, R26, R27, R28, R32: 220; AXIAL-0.3
R34: 330k; AXIAL-0.3
R36: 470k; AXIAL-0.3
R37: 10k; AXIAL-0.3
R38: 56k; AXIAL-0.3
RASPI_PORT1, RASPI_PORT2: PINHD-2X20; 2X20
REL1, REL2, REL3: 12v; AB_ELECTROMAGNETIC_RELAY
RFID, RFID1, RFID2, RFID3, RFID4: AB_8PIN_LOC_CONNECTOR
RN1: G07R; SIL8
RN6, RN7: G08R; SIL9
SERVO1, SERVO2, SERVO3, SERVO4: AB_3PIN_LOC_CONNECTOR
SHARP1, SHARP2, SHARP3: AB_3PIN_LOC_CONNECTOR
SW1: SW_DIP-6; EDG-06
TR14, TR15, TR16, TR17, TR18, TR19, TR20, TR21, TR22, TR23, TR24: BC547; TO92
U45, U67: AB_RIGHT_TER_BLK
U$1, U$17, U$31, U$33, U$40, U$41, U$50, U$51, U$62: AB_JUMPER_ONE_WAY
U$2: AB_16X2_LCD_DISPLAY
U$3, U$6, U$9: AB_VNH2SP30; AB_VNH2SP30_MODULE
U$4: ESP8266_NODEMCU_BY_AB; AB_ESP8266_BREAKOUT
U$5: AB_RASPBERRY_PI_3
U$7: AB_LM2596_BUCK_CONVERTER
U$8: AB_XL6009_BOOST_CONVERTER; AB_XL6009E1_BOOST_CONVERTER
U$10: AB_GY87; AB_IMU_GY87
U$11: AB_BLUETOOTH_HC05
U$12: AB_USB_HOST_SHIELD_ARDUINO
U$13: AB_XL4015_5A_; AB_XL_4015_5A_BUCK
U$14, U$15, U$16, U$32: AB_SW
U$18, U$19, U$20: AB_MCP_73831_LIPO_CHARGER
U$21, U$22, U$23, U$25, U$26, U$27: 4.7 uF; AB_POL_CAP
U$24: AB_0.91_INCH_I2C_DISPLAY; AB_0.91INCH_I2C_DISPLAY
U$28, U$39: AB_BUZZER
U$29: 10 uF; AB_POL_CAP
U$30: AB_JUMPER_TWO_WAY
U$34, U$37, U$38: 220uF; AB_POL_CAP
U$35: AB_ARDUINO_NANO
U$36: AB_SCREW_TERMINAL_5MM_2PIN
U$42, U$48: AB_7PIN_LOC_CONNECTOR
U$43: AB_8PIN_LOC_CONNECTOR
U$44, U$46, U$47: AB_7805_FLAT
U$45: AB_5PIN_LOC_CONNECTOR
U$49: AB_4PIN_LOC_CONNECTOR
U$52, U$53: AB_10PIN_LOC_CONNECTOR
U$54, U$55, U$56, U$57, U$58, U$59, U$60, U$61, U$63, U$64: AB_PLATED_DRILL_160MIL
ULN_SIG: AB_3PIN_LOC_CONNECTOR
V-P: AB_RIGHT_TER_BLK_3PIN

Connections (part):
5VA: A.1, ENA.2, ENB.2, G_P2.A, IRH1.P$1 (1), IRH2.P$1 (1), IRH3.P$1 (1), NANO.1, NODEMCU.2, R17.P$1 (1), U$2.VIN, U$24.VCC, U$31.2
5VB: B.1, CEL1RO.P$1 (1), CEL2RO.P$1 (1), CEL3RO.P$1 (1), ENA1.1, RN1.1, SHARP1.1, SHARP2.1, SHARP3.1, U$14.O1, U$50.1
7VA: A.2, ATMEGA_2560.VIN, NODEMCU.1, SERVO1.2, SERVO2.2, SERVO3.2, SERVO4.2, U$4.VIN, U$12.VIN, U$35.VIN
7VB: B.2, U$16.O1
+5V: BAT6.1, C5.1, CEL2RO1.P$2 (2), IC3.7, IC3.20, JP3.4, U$50.2
-: ATMEGA_2560.-, U$12.-
A0: ATMEGA_2560.A0, CON2B1.7, RFID3.8, U$12.A0
A0B: CON2B2.7, LSA_2.4
A1: ATMEGA_2560.A1, CON2B1.8, RFID3.7, U$12.A1
A1B: CON2B2.8, SHARP1.3
A2: ATMEGA_2560.A2, CON2B1.9, RFID3.6, U$12.A2
A2B: CON2B2.9, SHARP2.3
A3: ATMEGA_2560.A3, CON2B1.10, RFID3.5, U$12.A3
A3B: CON2B2.10, SHARP3.3
A4: ATMEGA_2560.A4, OISO4.5, RFID3.4, RN6.9, TR17.3 (C), U$12.A4
A5: ATMEGA_2560.A5, OISO4.4, RFID3.3, RN6.7, TR18.3 (C), U$12.A5
A6: ATMEGA_2560.A6, OISO4.3, RFID3.2, RN6.5, TR19.3 (C)
A7: ATMEGA_2560.A7, OISO4.2, RFID3.1, RN6.3, TR20.3 (C)
A8: ATMEGA_2560.A8, OISO6.1, RFID4.8, RN7.9, TR21.3 (C)
A9: ATMEGA_2560.A9, OISO6.2, RFID4.7, RN7.7, TR22.3 (C)
A10: ATMEGA_2560.A10, OISO6.3, RFID4.6, RN7.5, TR23.3 (C)
A11: ATMEGA_2560.A11, OISO6.4, RFID4.5, RN7.3, TR24.3 (C)
AREF: ATMEGA_2560.AREF, U$12.AREF
A_3V3: ATMEGA_2560.3V3, U$12.3V3
A_5V: ATMEGA_2560.5V, ENC_PULL.1, RN6.1, RN7.1, U$10.VIN, U$11.5V, U$12.5V1, U$31.1, U$39.+
A_5V1: ATMEGA_2560.5V3, U$12.5V
A_GND1: ATMEGA_2560.GND, U$12.GND2
A_GND2: ATMEGA_2560.GND5, U$12.GND1 (GD)
B_RX: BLUETOOTH.3, SW1.11, U$11.RX
B_TX: BLUETOOTH.4, SW1.12, U$11.TX
CS+: CS.1, REL1.COM, REL2.COM, REL3.COM, U$36.1
D2: U$12.D2
D3: U$12.D3
D4: U$12.D4
D5: ATMEGA_2560.D5, CON1A.10, RFID1.6, U$12.D5
D5B: CON1B.10, PPR_R1.P$2 (2)
D6: ATMEGA_2560.D6, RFID1.7, SERVO1.3, U$12.D6
D7: ATMEGA_2560.D7, RFID1.8, U$12.D7
D8: ATMEGA_2560.D8, U$12.D8, U$42.1
D9: ATMEGA_2560.D9, U$12.D9, U$42.2
D10: ATMEGA_2560.D10, U$12.D10, U$42.3
D11: ATMEGA_2560.D11, SERVO3.3, U$12.D11, U$42.4
D12: ATMEGA_2560.D12, SERVO2.3, U$12.D12, U$42.5
D13: ATMEGA_2560.D13, SERVO4.3, U$12.D13, U$42.6
D22: ATMEGA_2560.D22, CON2A.7, JP2.1
D22B: CON2B.7, IC1.4
D23: ATMEGA_2560.D23, CON2A.6, JP2.2
D23B: CON2B.6, IC1.5
D24: ATMEGA_2560.D24, CON2A.5, JP2.3
D24B: CON2B.5, IC1.6
D25: ATMEGA_2560.D25, CON2A.4, JP2.4
D25B: CON2B.4, IC1.7
D26: ATMEGA_2560.D26, JP2.5, U$2.RS
D27: ATMEGA_2560.D27, JP2.6, U$2.EN
D28: ATMEGA_2560.D28, JP2.7, U$2.D4
D29: ATMEGA_2560.D29, JP2.8, U$2.D5
D30: ATMEGA_2560.D30, JP2.9, U$2.D6
D31: ATMEGA_2560.D31, JP2.10, U$2.D7
D32: ATMEGA_2560.D32, JP2.11, OISO1.5, R32.P$2 (2)
D33: ATMEGA_2560.D33, JP2.12, OISO1.4, R18.P$2 (2)
D34: ATMEGA_2560.D34, JP2.13, OISO1.3, R19.P$2 (2)
D35: ATMEGA_2560.D35, JP2.14, OISO1.2, R20.P$2 (2)
D36: ATMEGA_2560.D36, CON2A.3, JP2.15
D36B: CON2B.3, D1.A, R4.P$2 (2)
D37: ATMEGA_2560.D37, CON2A.2, JP2.16
D37B: CON2B.2, D2.A, R10.P$2 (2)
D38: ATMEGA_2560.D38, CON2A.1, JP2.17
D38B: CON2B.1, D3.A, R11.P$2 (2)
D39: ATMEGA_2560.D39, CON2B1.2, JP2.18
D39B: CON2B2.2, LSA_2.5
D40: ATMEGA_2560.D40, CON1A.9, JP2.19
D40B: CON1B.9, U$6.INA
D41: ATMEGA_2560.D41, CON1A.8, JP2.20
D41B: CON1B.8, U$6.INB
D42: ATMEGA_2560.D42, CON1A.6, JP2.21
D42B: CON1B.6, U$3.INA
D43: ATMEGA_2560.D43, CON1A.5, JP2.22
D43B: CON1B.5, U$3.INB
D44: ATMEGA_2560.D44, CON1A.4, JP2.23
D44B: CON1B.4, U$3.PWM
D45: ATMEGA_2560.D45, CON1A.7, JP2.24
D45B: CON1B.7, U$6.PWM
D46: ATMEGA_2560.D46, CON1A.1, JP2.25
D46B: CON1B.1, U$9.PWM
D47: ATMEGA_2560.D47, CON1A.3, JP2.26
D47B: CON1B.3, U$9.INB
D48: ATMEGA_2560.D48, CON1A.2, JP2.27
D48B: CON1B.2, U$9.INA
D49: ATMEGA_2560.D49, JP2.28, U$39.-
D50: ATMEGA_2560.D50
D51: ATMEGA_2560.D51
D52: ATMEGA_2560.D52
D53: ATMEGA_2560.D53
D_GND: ATMEGA_2560.GND2, CON2B1.1, ENA.1, ENB.1, G_P2.E, IC8.2 (CATHODE_1), IC8.4 (CATHODE_2), IC8.6 (CATHODE_3), IC8.8 (CATHODE_4), IC9.9 (EMITTER_1), IC9.11 (EMITTER_2), IC9.13 (EMITTER_3), IC9.15 (EMITTER_4), IC10.9 (EMITTER_1), IC10.11 (EMITTER_2), IC10.13 (EMITTER_3), IC10.15 (EMITTER_4), OISO1.1, OISO4.1, OISO6.5, RFID.3, SERVO1.1, SERVO2.1, SERVO3.1, SERVO4.1, TR17.1 (E), TR18.1 (E), TR19.1 (E), TR20.1 (E), TR21.1 (E), TR22.1 (E), TR23.1 (E), TR24.1 (E), U$2.GND, U$2.L-, U$2.R/W, U$4.GND2, U$10.GND, U$11.GND, U$12.GND, U$17.1, U$24.GND, U$35.GND1, U$42.7, U$62.2
D_GNDB: CON2B2.1, C_GND.1
GND: BALANCE.1, BALANCE1.1, BAT1.2, C1.1, C3.1, C4.1, CEL1RC.P$1 (1), CEL2RC.P$1 (1), CEL3RC.P$1 (1), CON2B2.6, CS.2, C_GND.2, D1.K (C), D2.K (C), D3.K (C), IC1.8, IC2.4, LSA_2.10, PROX1.1, PROX2.1, PROX3.1, R5.P$1 (1), R6.P$1 (1), R7.P$1 (1), R34.P$1 (1), R36.P$1 (1), R38.P$1 (1), SHARP1.2, SHARP2.2, SHARP3.2, U$3.GND, U$3.IN-, U$6.GND, U$6.IN-, U$7.IN-, U$7.OUT-, U$8.IN-, U$8.OUT-, U$9.GND, U$9.IN-, U$13.IN-, U$13.OUT-, U$18.VSS, U$19.VSS, U$20.VSS, U$23.1, U$25.1, U$26.1, U$27.1, U$29.2, U$33.2, U$34.1, U$36.2, U$37.1, U$38.1, U$44.2 (GND), U$46.2 (GND), U$47.2 (GND), U$51.1, V-P.1
GNDA: ATMEGA_2560.GND1, CON2B1.6, IRL1.P$1 (1), IRL2.P$1 (1), IRL3.P$1 (1), MEGA_RST.3 (2), M_RST.3 (2), N_RST.3 (2), U$4.GND3, U$12.GND3, U$35.GND, U$62.1
GPIO2: RASPI_PORT1.3, RASPI_PORT2.37
GPIO3: RASPI_PORT1.5, RASPI_PORT2.35
GPIO4: RASPI_PORT1.7, RASPI_PORT2.33
GPIO5: RASPI_PORT1.29, RASPI_PORT2.11
GPIO6: OISO3.5, R21.P$2 (2), RASPI_PORT1.31, RASPI_PORT2.9
GPIO7: RASPI_PORT1.26, RASPI_PORT2.16
GPIO8: RASPI_PORT1.24, RASPI_PORT2.18
GPIO9: RASPI_PORT1.21, RASPI_PORT2.19
GPIO10: RASPI_PORT1.19, RASPI_PORT2.21
GPIO11: RASPI_PORT1.23, RASPI_PORT2.17
GPIO12: OISO3.4, R22.P$2 (2), RASPI_PORT1.32, RASPI_PORT2.10
GPIO13: OISO3.3, R23.P$2 (2), RASPI_PORT1.33, RASPI_PORT2.7
GPIO14: RASPI_PORT1.8, RASPI_PORT2.34, SW1.8
GPIO15: RASPI_PORT1.10, RASPI_PORT2.32, SW1.7
GPIO16: OISO5.5, R25.P$2 (2), RASPI_PORT1.36, RASPI_PORT2.6
GPIO17: RASPI_PORT1.11, RASPI_PORT2.29
GPIO18: RASPI_PORT1.12, RASPI_PORT2.30
GPIO19: OISO3.2, R24.P$2 (2), RASPI_PORT1.35, RASPI_PORT2.5
GPIO20: OISO5.3, R27.P$2 (2), RASPI_PORT1.38, RASPI_PORT2.4
GPIO21: OISO5.2, R28.P$2 (2), RASPI_PORT1.40, RASPI_PORT2.2
GPIO22: 10K.7, OISO2.4, RASPI_PORT1.15, RASPI_PORT2.25, TR14.3 (C)
GPIO23: 10K.5, OISO2.3, RASPI_PORT1.16, RASPI_PORT2.26, TR15.3 (C)
GPIO24: 10K.3, OISO2.2, RASPI_PORT1.18, RASPI_PORT2.24, TR16.3 (C)
GPIO25: RASPI_PORT1.22, RASPI_PORT2.20
GPIO26: OISO5.4, R26.P$2 (2), RASPI_PORT1.37, RASPI_PORT2.3
GPIO27: 10K.9, BC547.3 (C), OISO2.5, RASPI_PORT1.13, RASPI_PORT2.27
I-P: IC2.6, IC2.7, V-P.2
ID_SC: RASPI_PORT1.28, RASPI_PORT2.14
ID_SD: RASPI_PORT1.27, RASPI_PORT2.13
IOREF: ATMEGA_2560.IOREF, U$12.VREF
M1A: M1.2, U$3.OA (OUTA)
M1B: M1.1, U$3.OB (OUTB)
M2A: M2.1, U$6.OA (OUTA)
M2B: M2.2, U$6.OB (OUTB)
M3A: M3.1, U$9.OA (OUTA)
M3B: M3.2, U$9.OB (OUTB)
MISO: ATMEGA_2560.MISO, U$12.MISO (MI)
MOSI: ATMEGA_2560.MOSI, U$12.MOSI (MO)
M_3V3: RFID.1, U$4.3V3
M_A0: ATMEGA_2560.A15, JP1.1, RFID4.1, U$4.A0
M_D0: ATMEGA_2560.D3, RFID1.4, U$4.D0, U$45.1
M_D1: RFID.2, U$4.D1, U$45.2
M_D2: RFID.8, U$4.D2, U$45.3
M_D3: ATMEGA_2560.A12, RFID4.4, U$4.D3, U$45.4
M_D4: ATMEGA_2560.A13, RFID4.3, U$4.D4, U$45.5
M_D5: RFID.7, U$4.D5, U$49.1
M_D6: RFID.5, U$4.D6, U$49.2
M_D7: RFID.6, U$4.D7, U$49.3
M_D8: ATMEGA_2560.A14, RFID4.2, U$4.D8, U$49.4
M_EN: U$4.EN
M_RST: M_RST.1, U$4.RST, U$30.1
M_RX: SW1.9, U$4.RX
M_TX: SW1.10, U$4.TX
unnamed: C1.2, U$7.OUT+, U$14.IP, U$34.2
unnamed: IC10.7 (ANODE_4), R28.P$1 (1)
unnamed: IC9.7 (ANODE_4), R24.P$1 (1)
unnamed: U$15.O1, V-P.3
unnamed: G_P2.S, U$2.VCON
unnamed: PROX1.2, U$44.1 (VIN)
unnamed: R4.P$1 (1), U$44.3 (VO)
unnamed: PROX3.2, U$47.1 (VIN)
unnamed: 10K.4, IC8.12 (COLLECTOR_2), TR15.2 (B)
unnamed: IC9.16 (COLLECTOR_4), RN6.8, TR17.2 (B)
unnamed: R11.P$1 (1), U$47.3 (VO)
unnamed: R2.P$2 (2), R34.P$2 (2), U$1.1
unnamed: EM_SW.1, U$33.1
unnamed: 10K.2, IC8.10 (COLLECTOR_1), TR16.2 (B)
unnamed: 10K.8, BC547.2 (B), IC8.16 (COLLECTOR_4)
unnamed: FUSE.OUT, U$32.IP
unnamed: R35.P$2 (2), R36.P$2 (2), U$40.1
unnamed: IC9.10 (COLLECTOR_1), RN6.2, TR20.2 (B)
unnamed: R17.P$2 (2), U$2.L+
unnamed: U$3.5V, U$3.EN
unnamed: U$6.5V, U$6.EN
unnamed: 10K.6, IC8.14 (COLLECTOR_3), TR14.2 (B)
unnamed: C3.2, U$8.OUT+, U$15.IP, U$37.2
unnamed: R37.P$2 (2), R38.P$2 (2), U$41.1
unnamed: IC9.12 (COLLECTOR_2), RN6.4, TR19.2 (B)
unnamed: IC9.14 (COLLECTOR_3), RN6.6, TR18.2 (B)
unnamed: U$9.5V, U$9.EN
unnamed: C4.2, U$13.OUT+, U$16.IP, U$38.2
unnamed: IC10.10 (COLLECTOR_1), RN7.2, TR24.2 (B)
unnamed: IC10.12 (COLLECTOR_2), RN7.4, TR23.2 (B)
unnamed: IC10.14 (COLLECTOR_3), RN7.6, TR22.2 (B)
unnamed: IC10.16 (COLLECTOR_4), RN7.8, TR21.2 (B)
unnamed: CEL2CO.A, CEL2RO.P$2 (2)
unnamed: IH3.A, IRH3.P$2 (2)
unnamed: CEL3CO.A, CEL3RO.P$2 (2)
unnamed: CEL3CC.K (C), CEL3RC.P$2 (2)
unnamed: CEL2CC.K (C), CEL2RC.P$2 (2)
unnamed: CEL1CO.A, CEL1RO.P$2 (2)
unnamed: CEL1CC.K (C), CEL1RC.P$2 (2)
unnamed: IL3.K (C), IRL3.P$2 (2)
unnamed: IH2.A, IRH2.P$2 (2)
unnamed: IL2.K (C), IRL2.P$2 (2)
unnamed: R7.P$2 (2), U$18.PROG
unnamed: IH1.A, IRH1.P$2 (2)
unnamed: R6.P$2 (2), U$19.PROG
unnamed: IL1.K (C), IRL1.P$2 (2)
unnamed: R5.P$2 (2), U$20.PROG
unnamed: C2.1, JP3.1
unnamed: L1.A, RN1.2
unnamed: L2.A, RN1.3
unnamed: L3.A, RN1.4
unnamed: L4.A, RN1.5
unnamed: L5.A, RN1.6
unnamed: L6.A, RN1.7
unnamed: L7.A, RN1.8
unnamed: PROX2.2, U$46.1 (VIN)
unnamed: R10.P$1 (1), U$46.3 (VO)
unnamed: IC8.1 (ANODE_1), R32.P$1 (1)
unnamed: IC8.3 (ANODE_2), R18.P$1 (1)
unnamed: IC8.5 (ANODE_3), R19.P$1 (1)
unnamed: IC8.7 (ANODE_4), R20.P$1 (1)
unnamed: IC9.1 (ANODE_1), R21.P$1 (1)
unnamed: IC9.3 (ANODE_2), R22.P$1 (1)
unnamed: IC9.5 (ANODE_3), R23.P$1 (1)
unnamed: IC10.1 (ANODE_1), R25.P$1 (1)
unnamed: IC10.3 (ANODE_2), R26.P$1 (1)
unnamed: IC10.5 (ANODE_3), R27.P$1 (1)
N_5V: NANO.2, U$28.+, U$35.5V
N_A0: CON2B1.3, U$35.A0, U$43.1
N_A0B: CON2B2.3, ENA1.4, U$1.2
N_A1: CON2B1.4, U$35.A1, U$43.2
N_A1B: CON2B2.4, ENA1.3, U$40.2
N_A2: CON2B1.5, U$35.A2, U$43.3
N_A2B: CON2B2.5, ENA1.2, U$41.2
N_A3: IH3.K (C), IL3.A, U$35.A3, U$43.4
N_A4: U$24.SDA, U$35.A4, U$43.5
N_A5: U$24.SCL, U$35.A5, U$43.6
N_A6: IH2.K (C), IL2.A, U$35.A6, U$43.7
N_A7: IH1.K (C), IL1.A, U$35.A7, U$43.8
N_D2: ENA.4, ENC_PULL.2, U$35.D2
N_D3: ENB.4, ENC_PULL.4, U$35.D3
N_D4: ENA.3, ENC_PULL.3, U$35.D4
N_D5: ENB.3, ENC_PULL.5, U$35.D5
N_D6: ATMEGA_2560.D2, RFID1.3, U$35.D6, U$48.1
N_D7: ATMEGA_2560.D4, RFID1.5, U$35.D7, U$48.2
N_D8: U$35.D8, U$48.3
N_D9: CON2A.10, U$35.D9, U$48.4
N_D9B: CON2B.10, IC1.1
N_D10: CON2A.9, U$35.D10, U$48.5
N_D10B: CON2B.9, IC1.2
N_D11: CON2A.8, U$35.D11, U$48.6
N_D11B: CON2B.8, IC1.3
N_D12: U$35.D12, U$48.7
N_D13: U$28.-, U$35.D13
N_RST: N_RST.1, U$30.2, U$35.RST
N_RX: BLUETOOTH.1, N-M.1, U$35.RX
N_TX: BLUETOOTH.2, N-M.2, U$35.TX
POS_1: IC2.5, PPR_R1.P$1 (1), U$29.1
RESET: C2.2, CEL2RO1.P$1 (1), IC3.1, MEGA_RST1.1
RO1: REL1.OUT_1, U$18.VDD, U$25.2
RO2: REL2.OUT_1, U$19.VDD, U$26.2
RO3: REL3.OUT_1, U$20.VDD, U$27.2
RST: ATMEGA_2560.RST, MEGA_RST.1, U$12.RST1, U$30.C
RST1: ATMEGA_2560.RST1, U$12.RST
RX0: ATMEGA_2560.RX0, RFID1.1, U$12.RX0 (RX)
RX1: ATMEGA_2560.RX1, N-M.3, RFID2.3, SW1.1
RX2: ATMEGA_2560.RX2, RFID2.5, SW1.3
RX3: ATMEGA_2560.RX3, RFID2.7, SW1.5
RXD: IC3.2, JP3.3, U$52.10
R_3V3: 10K.1, RASPI_PORT1.1, RASPI_PORT2.39
R_3V31: RASPI_PORT1.17, RASPI_PORT2.23
R_5V: RASPI_PORT1.2, RASPI_PORT2.40
R_5V1: RASPI_PORT1.4, RASPI_PORT2.38
R_GND: BC547.1 (E), IC8.9 (EMITTER_1), IC8.11 (EMITTER_2), IC8.13 (EMITTER_3), IC8.15 (EMITTER_4), IC9.2 (CATHODE_1), IC9.4 (CATHODE_2), IC9.6 (CATHODE_3), IC9.8 (CATHODE_4), IC10.2 (CATHODE_1), IC10.4 (CATHODE_2), IC10.6 (CATHODE_3), IC10.8 (CATHODE_4), OISO2.1, OISO3.1, OISO5.1, RASPI_PORT1.9, RASPI_PORT2.31, TR14.1 (E), TR15.1 (E), TR16.1 (E), U$17.2
R_GND1: RASPI_PORT1.25, RASPI_PORT2.15
R_GND2: RASPI_PORT1.39, RASPI_PORT2.1
R_GND3: RASPI_PORT1.34, RASPI_PORT2.8
R_GND4: RASPI_PORT1.30, RASPI_PORT2.12
R_GND5: RASPI_PORT1.20, RASPI_PORT2.22
R_GND6: RASPI_PORT1.14, RASPI_PORT2.28
R_GND7: RASPI_PORT1.6, RASPI_PORT2.36
SCK: ATMEGA_2560.SCK, U$12.SCK (SC)
SCL: ATMEGA_2560.SCL, RFID2.1, U$10.SCL
SCLU: ATMEGA_2560.SCLU, U$12.SCL
SDA: ATMEGA_2560.SDA, RFID2.2, U$10.SDA
SDAU: ATMEGA_2560.SDAU, U$12.SDA
STAT_1: CEL1CC.A, CEL1CO.K (C), U$18.STAT
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

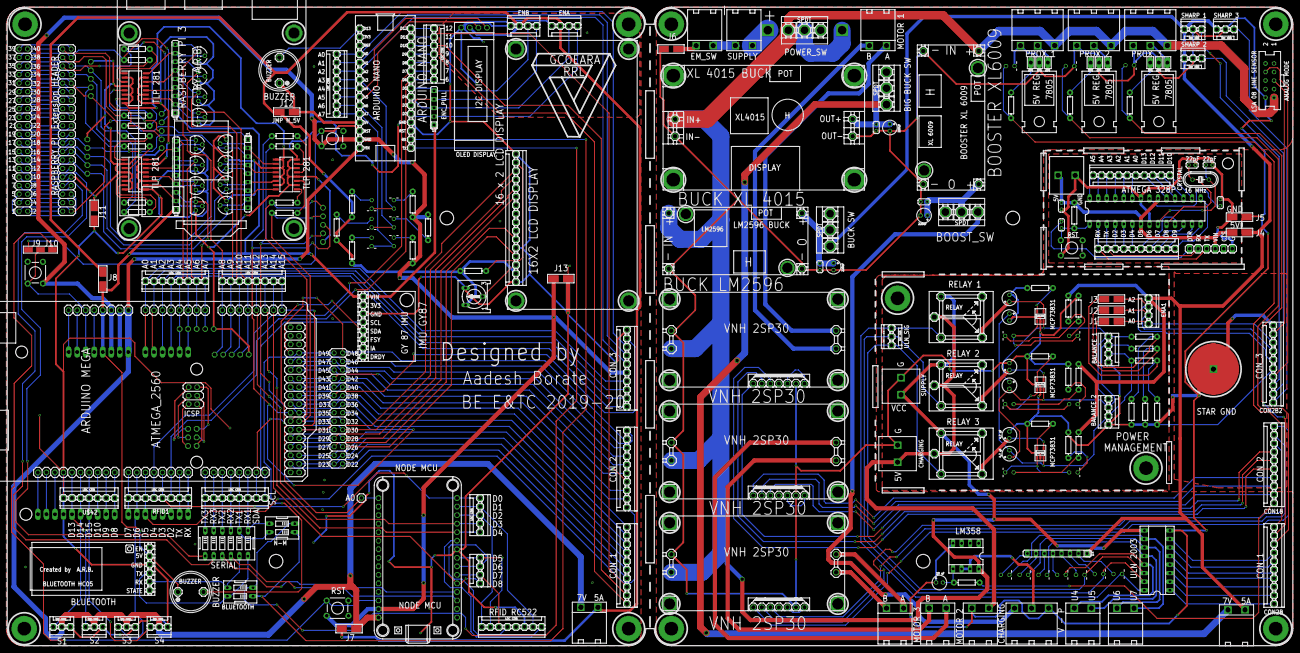
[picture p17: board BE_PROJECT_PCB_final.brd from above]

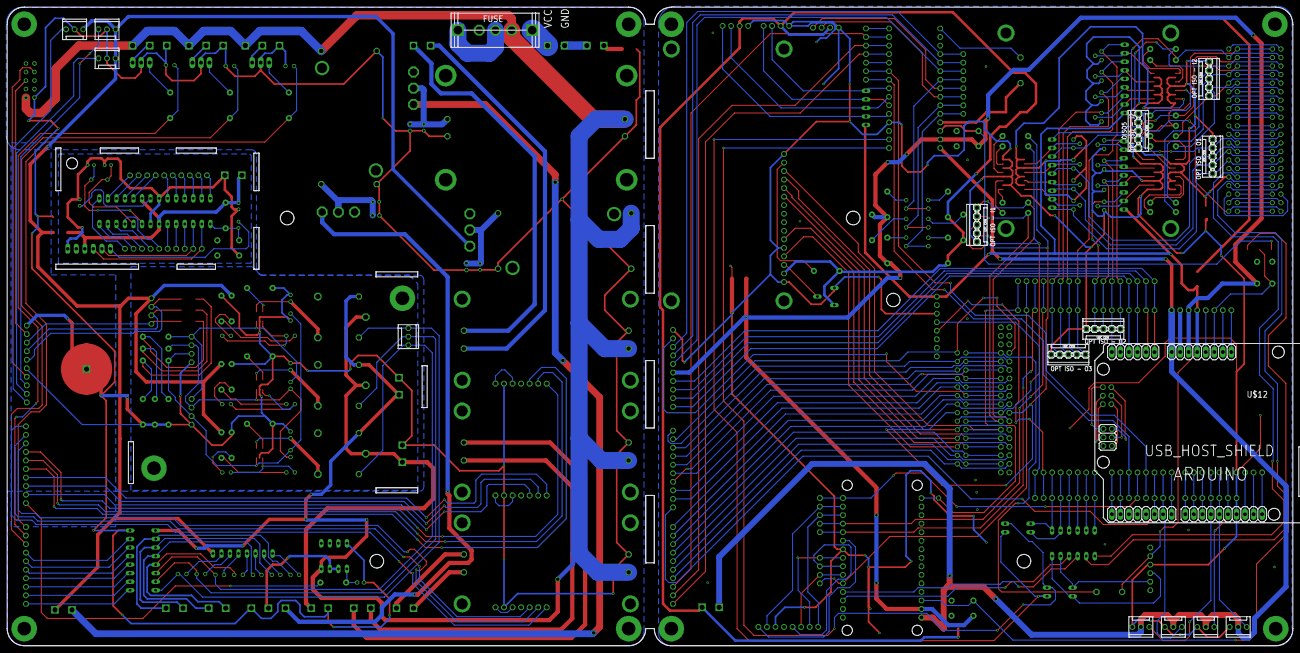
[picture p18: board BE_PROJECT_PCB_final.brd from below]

Board: 2 copper layers, 382.5 x 190.0 mm, 225 parts (8 on the bottom side), 311 nets.

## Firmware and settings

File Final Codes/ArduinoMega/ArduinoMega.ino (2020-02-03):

// Inclusion of libraries.
#include<math.h>
#include <Wire.h>
#include <I2Cdev.h>
#include <L3GD20H.h>
#include <LiquidCrystal.h>

// GPIO pin declarations.
int PWM_F = 44;
int PWM_L = 46;
int PWM_R = 45;
int DR_F1 = 43;
int DR_F2 = 42;
int DR_L1 = 47;
int DR_L2 = 48;
int DR_R1 = 41;
int DR_R2 = 40;
int RS = 26;
int EN = 27;
int D4 = 28;
int D5 = 29;
int D6 = 30;
int D7 = 31;
int Green = 23;
int Red = 24;
int Blue = 25;
int VL = 0;
int Buzzer = 49;
int servo = 12;
int count = 1;
// LCD pin declaration
LiquidCrystal lcd(26, 27, 28, 29, 30, 31);
// Object declarations
L3GD20H gyro;
// Variable Declarations
int16_t avx, avy, avz;
long int timer , tp;
float timestep, yaw;
float reading = 0;
char SER_IP = 'S';
float theta = 0 * M_PI / 180;
float V1, V2, V3;
float Vx, Vy;
float V = 80;
float timeStep = 0.01;
float error = 0;
float PID = 0;
float P, I, D;
float preverror = 0;
float kp = 15;
float ki = 0.001;
float kd = 161 ;
float setpoint = 0;
// Function declarations
void Clockwise();
void AntiClockwise();
void V1_Clockwise();
void V2_Clockwise();
void V3_Clockwise();
void V1_AntiClockwise();
void V2_AntiClockwise();
void V3_AntiClockwise();
void setup()
{
  /*
    Function Name:   pinMode(pin, mode)
    Input:    pin: the Arduino pin number to set the mode of.
              mode: INPUT, OUTPUT, or INPUT_PULLUP.
    Output:     Nothing
    Logic:    The code makes the digital "pin" available for either INPUT/INPUT_PULLUP or OUTPUT.
    Example Call:   pinMode(PWM_F, OUTPUT);
  */

  pinMode(PWM_F, OUTPUT);
  pinMode(DR_F1, OUTPUT);
  pinMode(DR_F2, OUTPUT);
  pinMode(PWM_L, OUTPUT);
  pinMode(DR_L1, OUTPUT);
  pinMode(DR_L2, OUTPUT);
  pinMode(PWM_R, OUTPUT);
  pinMode(DR_R1, OUTPUT);
  pinMode(DR_R1, OUTPUT);
  pinMode(Green, OUTPUT);
  pinMode(Red, OUTPUT);
  pinMode(Blue, OUTPUT);
  pinMode(Buzzer, OUTPUT);
  pinMode(servo, OUTPUT);
  lcd.begin(16, 2);
  digitalWrite(Buzzer, HIGH);

  Wire.begin();
  Serial.begin(115200);
  Serial1.begin(9600);
  Serial.println("Initializing I2C devices...");
  gyro.initialize();
  Serial.println("Testing device connections...");
  Serial.println(gyro.testConnection() ? "L3GD20H connection successful" : "L3GD20H connection failed");
  gyro.setEndianMode(not gyro.getEndianMode());
  Serial.print("EndianMode: ");
  Serial.print(gyro.getEndianMode());
  gyro.setEndianMode(not gyro.getEndianMode());
  Serial.print(" EndianMode: ");
  Serial.println(gyro.getEndianMode());
  gyro.setFullScale(2000);
  gyro.setOutputDataRate(100);
  gyro.setBlockDataUpdateEnabled(1);
  lcd.setCursor(0, 0);
  lcd.print("         AGV");
}


void loop() {

  timer = millis();
  timestep = (timer - tp) / 1000.0;
  tp = timer;
  gyro.getAngularVelocity(&avx, &avy, &avz);
  reading = (avz) * 0.07;
  if (abs(avz) < 25)reading = 0;
  yaw = yaw + reading * timestep;
  Serial.println(yaw);
  if (SER_IP == 'X')
  {
    setpoint = (setpoint + 90);
  }

  if (Serial1.available() > 0)
  {
    SER_IP = Serial1.read();
  }
  if (SER_IP == 'F')
  {
    theta = 90 * M_PI / 180;
    count = 1;
  }
  if (SER_IP == 'B')
  {
    theta = 270 * M_PI / 180;
    count = 1;
  }
  if (SER_IP == 'L')
  {
    theta = 180 * M_PI / 180;
    count = 1;
  }
  if (SER_IP == 'R')
  {
    theta = 0 * M_PI / 180;
    count = 1;
  }
  if (SER_IP == 'G')
  {
    theta = 135 * M_PI / 180;
    count = 1;
  }
  if (SER_IP == 'I')
  {
    theta = 45 * M_PI / 180;
    count = 1;
  }
  if (SER_IP == 'H')
  {
    //    theta = 225 * M_PI / 180;
    //    count = 1;
    digitalWrite(servo, HIGH);
    delayMicroseconds(2300);
    digitalWrite(servo, LOW);
    delay(20);

  }
  if (SER_IP == 'J')
  {
    //    theta = 315 * M_PI / 180;
    //    count = 1;
    digitalWrite(servo, HIGH);
    delayMicroseconds(1500);
    digitalWrite(servo, LOW);
    delay(20);
  }

  if (SER_IP >= '1' && SER_IP <= '9')
  {
    VL = SER_IP ;
    count = 1;
  }
  if (SER_IP == 'W')
  {
    digitalWrite(Green, HIGH);
    digitalWrite(Red, HIGH);
    digitalWrite(Blue, HIGH);
    count = 1;
  }
  if (SER_IP == 'w')
  {

    digitalWrite(Green, LOW);
    digitalWrite(Red, LOW);
    digitalWrite(Blue, LOW);
    count = 1;

  }
  if (SER_IP == 'U')
  {

    digitalWrite(Red, HIGH);
    count = 1;

  }
  if (SER_IP == 'u')
  {

    digitalWrite(Red, LOW);
    count = 1;

  }
  if (SER_IP == 'V')
  {
    digitalWrite(Buzzer, LOW);
    count = 1;
  }
  if (SER_IP == 'v')
  {
    digitalWrite(Buzzer, HIGH);
    count = 1;
  }

  V = map(VL , 49, 58, 0, 255);
  if (V == -1388)
  {
    V = 0;
  }
  Serial.println(V);
  error = yaw - setpoint;
  P = kp * error;
  I = I + (error * ki);
  D = kd * (error - preverror);
  PID = P + I + D;
  preverror = error;
  lcd.setCursor(0, 0);
  lcd.print(V1 + PID);
  lcd.print("  ");
  lcd.print(yaw);
  lcd.setCursor(0, 1);
  lcd.print(V2 + PID);
  lcd.print("  ");
  lcd.print(V3 + PID);

  if (SER_IP == 'S')
  {
    V = 0;
  }
  Vx = V * cos(theta);
  Vy = - V * sin(theta);

  V1 = Vx + PID;
  V2 = -(Vx * 0.5 + Vy * 0.866) + PID ;
  V3 = -Vx * 0.5 + Vy * 0.866 + PID;

  if (V1 >= 0)
  {
    V1_Clockwise();
  }
  else
  {
    V1_AntiClockwise();
  }
  if (V2 >= 0)
  {
    V2_Clockwise();
  }
  else
  {
    V2_AntiClockwise();
  }
  if (V3 >= 0)
  {
    V3_Clockwise();
  }
  else
  {
    V3_AntiClockwise();
  }

}
/*
    Function Name: V1_Clockwise()
    Input: None
    Output: None
    Logic: For driving motor in Clockwise direction.
    Example Call: V1_Clockwise()
*/
void V1_Clockwise()
{
  analogWrite(PWM_F, abs(V1));
  digitalWrite(DR_F1, HIGH);
  digitalWrite(DR_F2, LOW);

}
/*
    Function Name: V2_Clockwise()
    Input: None
    Output: None
    Logic: For driving motor in Clockwise direction.
    Example Call: V2_Clockwise()
*/
void V2_Clockwise()
{

  analogWrite(PWM_L, abs(V2));
  digitalWrite(DR_L1, HIGH);
  digitalWrite(DR_L2, LOW);


}
/*
    Function Name: V3_Clockwise()
    Input: None
    Output: None
    Logic: For driving motor in Clockwise direction.
    Example Call: V3_Clockwise()
*/
void V3_Clockwise()
{

  analogWrite(PWM_R, abs(V3));
  digitalWrite(DR_R1, HIGH);
  digitalWrite(DR_R2, LOW);

}
/*
    Function Name: V1_AntiClockwise()
    Input: None
    Output: None
    Logic: For driving motor in Clockwise direction.
    Example Call: V1_AntiClockwise();
*/

void V1_AntiClockwise()
{
  analogWrite(PWM_F, abs(V1));
  digitalWrite(DR_F1, LOW);
  digitalWrite(DR_F2, HIGH);
}
/*
    Function Name: V2_AntiClockwise()
    Input: None
    Output: None
    Logic: For driving motor in Clockwise direction.
    Example Call: V2_AntiClockwise();
*/
void V2_AntiClockwise()
{

  analogWrite(PWM_L, abs(V2));
  digitalWrite(DR_L1, LOW);
  digitalWrite(DR_L2, HIGH);
}
/*
    Function Name: V3_AntiClockwise()
    Input: None
    Output: None
    Logic: For driving motor in Clockwise direction.
    Example Call: V3_AntiClockwise();
*/
void V3_AntiClockwise()
{
  analogWrite(PWM_R, abs(V3));
  digitalWrite(DR_R1, LOW);
  digitalWrite(DR_R2, HIGH);
}

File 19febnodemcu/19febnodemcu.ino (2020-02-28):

#ifdef ESP32
#include <WiFi.h>
#include <ESPAsyncWebServer.h>
#include <SPIFFS.h>
#else
#include <Arduino.h>
#include <ESP8266WiFi.h>
#include <Hash.h>
#include <ESPAsyncTCP.h>
#include <ESPAsyncWebServer.h>
#include "FS.h"
#endif

AsyncWebServer server(80);

// REPLACE WITH YOUR NETWORK CREDENTIALS
const char* ssid = "unnati_laptop";
const char* password = "unnatirk789";

const char* PARAM_INPUT_1 = "Start_Point";
const char* PARAM_INPUT_2 = "End_Point";

// HTML web page
const char index_html[] PROGMEM = R"rawliteral(
<!DOCTYPE HTML><html><head>
  <title>GCOEARA AGV</title>
  <meta name="viewport" content="width=device-width, initial-scale=1">
  <style>
  body {
    background-color: lightblue;
  }
  p{
  color: Black;
  text-align: center;
  }
  p{
    font-family: Times new roman;
    font-size: 30px;
  } 
  </style>
  </head><body>
  <br>   
  <center><img src="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

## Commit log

2019-12-17 Arduino Code Folder created with info
2019-12-17 Created Raspberry Pi Folder
2019-12-28 Arduino Code (Optoisolator Testing)
2020-01-13 PCB Files
    [BE_PROJECT_PCB.brd, BE_PROJECT_PCB.sch]
2020-01-13 Gerber Files Created in Eagle
2020-01-13 PCB Files Final
    [BE_PROJECT_PCB_final.brd, BE_PROJECT_PCB_final.sch]
2020-02-03 Arduino code folder creation
2020-02-07 serial arduino pi
2020-02-18 data transmissionn to arduino
2020-02-27 Updated Arduino code before Regional Finals
2020-03-09 Updated code with frame concept
2020-03-09 Updated Arduino code with respect to time step
2020-03-12 Two PID

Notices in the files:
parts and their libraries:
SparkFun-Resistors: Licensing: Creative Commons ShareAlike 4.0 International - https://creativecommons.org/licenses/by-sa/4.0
